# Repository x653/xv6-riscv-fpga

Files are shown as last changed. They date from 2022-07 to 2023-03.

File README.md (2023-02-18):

# xv6-riscv-fpga

Build a RISC-V computer system on fpga iCE40HX8K-EVB and run UNIX xv6 using only FOSS (free and open source hard- and software).

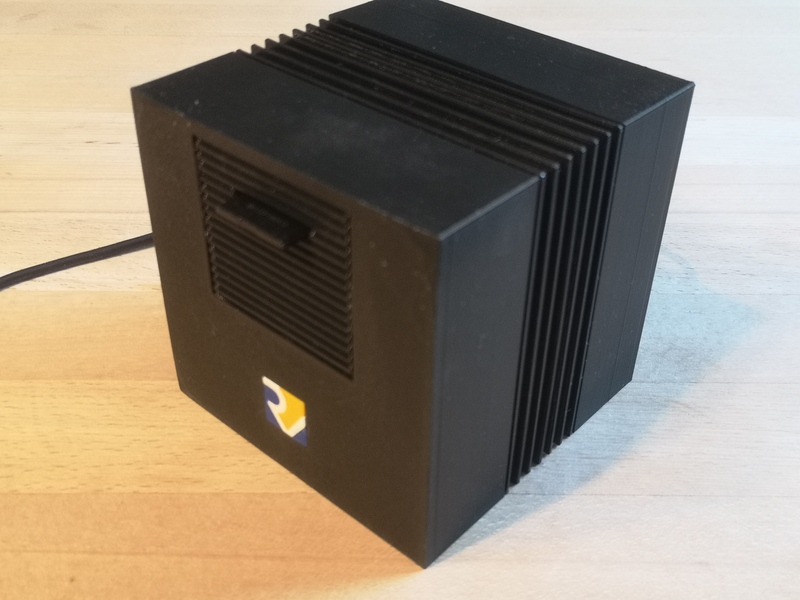
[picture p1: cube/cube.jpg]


xv6-riscv is a simple educational UNIX operating system written in ANSI-C developed and used at MIT in courses to teach operating systems. The original code is implemented for RISC-V 64 bit CPU.

In this project we will build a minimal computer system based on an fpga board capable of running UNIX xv6. We will implement only the smaller 32 bit version of RISC-V CPU and we will drop all features not explicit needed to run xv6, like floating point operation and even multiplication in hardware. The remaining core is called rv32ia_zicsr and implements only a minimal command set:

- I: Integer and logic computation

- A: atomic commands

- zicsr: control register

- privileged modes (M/S/U): machine mode, supervisor mode and user mode

- virtual memory mapping

Although our CPU does not implement multiplication and floating point operation in hardware, we will see, that all this can be done in software by linking the appropriate gcc librarys. The final computer will be able to boot UNIX xv6 and even run a homemade LISP interpreter, which is cabable of doing numerical computations even on floating point numbers.

## 01_hardware

The hardware consists of three little boards available at Olimex Ltd.

* iCE40HX8K-EVB: This development board contains the fpga chip iCE40HX8K plus a 512k Byte memory chip used as RAM.

* Olimexino 32u4: This arduino like board is used
  
  1. as programmer, to upload the fpga bitstream file to the iCE40HX8K-EVB board.
  
  2. as UART bridge, to connect a terminal to the RISCV-V CPU running UNIX xv6.
  
  3. to power everything over USB through the UEXT cable, connect the solder jumper `3.3V_E1` on iCE40HX8K-EVB. (compare schematic of [iCE40HX8K-EVB](doc/iCE40HX8K-EVB_Rev_B.pdf))

* SD-CARD: This little board holds an SD-Card containing the complete file system of UNIX xv6.

Connect the three boards according to the following picture:

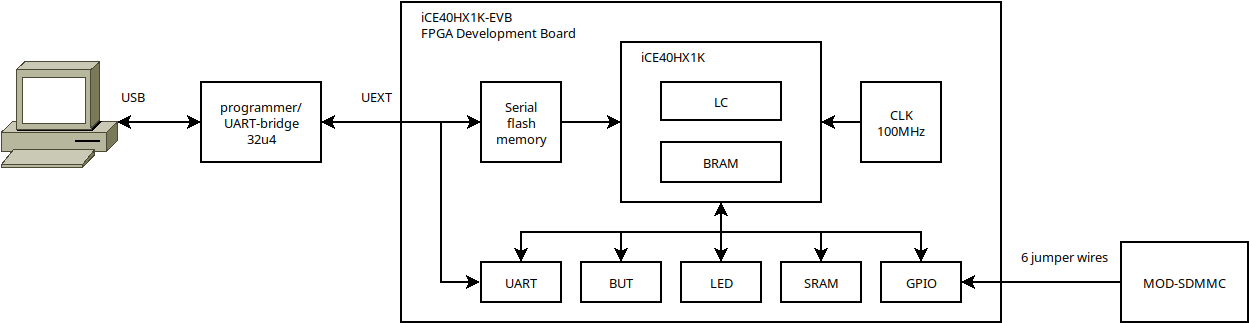
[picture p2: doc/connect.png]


* USB mini cable from Computer to Olimexino 32u4

* IDC10 cable from Olimexino 32u4 to iCE40HX8K-EVB

* 6 jumper wires from iCE40HX8K-EVB to MOD-SDMMC

| wire | iCE40HX8K-EVB<br/>JTAG1 connector | MOD-SDMMC<br/>UEXT connector |
| --- | --- | --- |
| +3.3V | 6 - VCC | 1 - VCC |
| GND | 5 - GND | 2 - GND |
| SDI - serial data in  | 2 - TDI (PIO1_00) | 7 - MISO |
| SDO - serial data out | 3 - TDO (PIO1_03) | 8 - MOSI |
| SCK - serial clock | 4 - TCK (PIO1_02) | 9 - SCK |
| CSX- chip select not  | 1 - TMS (PIO1_01) | 10 - #SS |

## 02_software

### 02.1_oss-cad-suite

The fpga iCE40HX8K has the nice property, that it can be programmed with FOSS free and open source software. This can be done with the toolchain project icestorm provided by Clifford Wold. The complete toolchain (yosys, icestorm, place and route, programmer) is available as bundle at [GitHub - YosysHQ/oss-cad-suite-build: Multi-platform nightly builds of open source digital design and verification tools](https://github.com/YosysHQ/oss-cad-suite-build/).

- Install oss-cad-suite and copy the folder to `/opt/oss-cad-suite`

### 02.1_gcc-toolchain for RISC-V

The toolchain with c-compiler can be downloaded from the following site. In order to be able to build code for the rv32ia_zicsr version we need a toolchain with multilib and gcc-libary implementation for rv32i.

Attention: Download rv64imc with multilib rv32i and copy folder to `/opt/riscv`

[GitHub - stnolting/riscv-gcc-prebuilt: 📦 Prebuilt RISC-V GCC toolchains for x64 Linux.](https://github.com/stnolting/riscv-gcc-prebuilt)

## 03_build

### 03.1_compile bootloader

* Build the firmware, which implements a bootloader, that reads the SD-CARD. The bootloader than seaches for an ELF file containing the kernel xv6. Loads the kernel into memory and starts the kernel. 

```
$ cd fpga/boot
$ make
```

### 03.2_synthesize and upload to fpga iCE40HX8K-EVB

The fpga iCE40HX8K contains the whole hardware of our computer system:

* CPU: RV32ia_zicsr

* BOOT: Memory preloaded with bootloader

* UART: Connects the terminal to xv6 shell

* SPI: Connects the SD-Card containing the file system

To build the fpga hardware connect your computer with the programmer Olimexino 32u4 and run:

```
$ cd fpga
$ make
```

### 03.3_compile xv6-riscv

* Build the software, composed of kernel and user programms and write everything on the file system. 

```
$ cd xv6-riscv
$ make
$ make fs.img
```

* Write the image `fs.img` on a SD-Card.

## 04_Run

### 04_1_run xv6

Now connect to RV32ia_zicsr with USB and start a terminal session (i.e. tio). Start RV32ia_zicsr and see the welcome message. Insert the SD-Card into the reader and see if RV32 can boot UNIX xv6 from the file system.

```
$ tio -m INLCRNL /dev/ttyACM0
 ___ ___ ___  ___  __   __
| _ \_ _/ __|/ __|_\ \ / /
|   /| |\__ \ (_|___\ V / 
|_|_\___|___/\___|   \_/  

Processor: rv32ia @32MHz V1.2

0x00001000 BOOT (12 KB)
0x02000000 CLINT
0x0C000000 PLIC
0x10000000 UART
0x10001000 SD-CARD
0x80000000 RAM (512 KB)

sb_magic 0x10203040.OK
e_magic  0x464c457f..OK
   p_type     p_addr     p_filesz   load
0  0x70000003 0x00000000 0x00000025 
1  0x00000001 0x80000000 0x00009138 OK
2  0x00000001 0x8000a000 0x0000003c OK
e_entry  0x80000000

Welcome to rv32ia 6th Edition UNIX

xv6 kernel is booting

init: starting sh
$ 
```

### 04.2_unix commands

Now that you have access to the shell you can launch UNIX commands.

```
$ ls
.              1 1 1296
..             1 1 1296
xv6.kernel     2 2 45676
README         2 3 1982
let            2 4 102
sqrt           2 5 443
sqrt2          2 6 467
fib            2 7 429
cat            2 8 4016
echo           2 9 3708
forktest       2 10 2128
grind          2 11 7952
grep           2 12 4612
init           2 13 3988
kill           2 14 3672
ln             2 15 3704
ls             2 16 4536
mkdir          2 17 3740
rm             2 18 3736
sh             2 19 7936
wc             2 20 4176
zombie         2 21 3592
stressfs       2 22 3896
uptime         2 23 3820
usertests      2 24 40660
lisp           2 25 23432
hello          2 26 3640
mem            2 27 4184
console        3 28 0
$ cat README
xv6 is a re-implementation of Dennis Ritchie's and Ken Thompson's Unix
Version 6 (v6).  xv6 loosely follows the structure and style of v6,
but is implemented for a modern RISC-V multiprocessor using ANSI C.

ACKNOWLEDGMENTS

xv6 is inspired by John Lions's Commentary on UNIX 6th Edition (Peer
to Peer Communications; ISBN: 1-57398-013-7; 1st edition (June 14,
2000)). See also https://pdos.csail.mit.edu/6.828/, which
provides pointers to on-line resources for v6.

The following people have made contributions: Russ Cox (context switching,
locking), Cliff Frey (MP), Xiao Yu (MP), Nickolai Zeldovich, and Austin
Clements.

We are also grateful for the bug reports and patches contributed by
Silas Boyd-Wickizer, Anton Burtsev, Dan Cross, Cody Cutler, Mike CAT,
Tej Chajed, eyalz800, Nelson Elhage, Saar Ettinger, Alice Ferrazzi,
Nathaniel Filardo, Peter Froehlich, Yakir Goaron,Shivam Handa, Bryan
Henry, Jim Huang, Alexander Kapshuk, Anders Kaseorg, kehao95, Wolfgang
Keller, Eddie Kohler, Austin Liew, Imbar Marinescu, Yandong Mao, Matan
Shabtay, Hitoshi Mitake, Carmi Merimovich, Mark Morrissey, mtasm, Joel
Nider, Greg Price, Ayan Shafqat, Eldar Sehayek, Yongming Shen, Cam
Tenny, tyfkda, Rafael Ubal, Warren Toomey, Stephen Tu, Pablo Ventura,
Xi Wang, Keiichi Watanabe, Nicolas Wolovick, wxdao, Grant Wu, Jindong
Zhang, Icenowy Zheng, and Zou Chang Wei.

The code in the files that constitute xv6 is
Copyright 2006-2019 Frans Kaashoek, Robert Morris, and Russ Cox.

ERROR REPORTS

Please send errors and suggestions to Frans Kaashoek and Robert Morris
(kaashoek,rtm@mit.edu). The main purpose of xv6 is as a teaching
operating system for MIT's 6.828, so we are more interested in
simplifications and clarifications than new features.

BUILDING AND RUNNING XV6

You will need a RISC-V "newlib" tool chain from
https://github.com/riscv/riscv-gnu-toolchain, and qemu compiled for
riscv64-softmmu. Once they are installed, and in your shell
search path, you can run "make qemu".
$ 
```

### 04.3_run LISP

and even run LISP on a computer system that runs UNIX on a home made CPU! 

```
$ lisp
lisp v6
sizeof pair: 2
size of number: 4
size of float: 4
size of (char*): 4
lisp> (+ 2 4)
6
lisp> 
```

## 05_cube

Finally we print case with a 3d-Printer. The case is a miniatur replica of the classic computer NeXTcube (https://en.wikipedia.org/wiki/NeXTcube). All components are mounted on trays, which can be pushed in the cube (10cm x 10cm x 10cm).

All the parts are modelled with free software tools.

- [blender](https://blender.org) is a very powerfull 3D modelling software. All parts of the cube are modelled with blender. You can edit the blender files and change details on the design. The blender-design files can than be exported to STL-format, a common 3D-file format used for 3D-printing.
- [prusa-slic3r](https://www.prusa3d.com). This is the slicer software for 3D-Printers from the manufacturer Prusa. This programm is used to convert the STL-files to printerspecific gcode-files.

The subfolder `files/` containes the blender files and the corresponging STL-files.

### 05.1_inside

The modules are mounted on trays with little screws (M3x5/M2.4x5 selfcutting). From left to right:

1. Olimexino 32u4: Programmer/UART bridge
2. iCE40HX8K-EVB: fpga development board
3. SD-Card reader
4. Thinker

# 

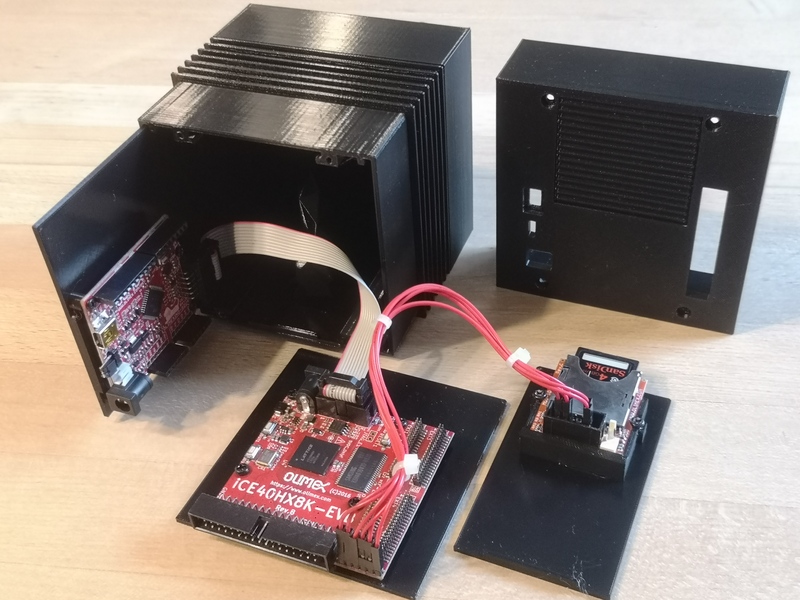
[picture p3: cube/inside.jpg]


### 05.2_rear

On the rear cover you see connectors for power supply (5V), 34 pin GPIO and the USB connector which has dual usage:

1. upload bitstream files to iCE40 fpga
2. communicate to Hack-Computer over UART

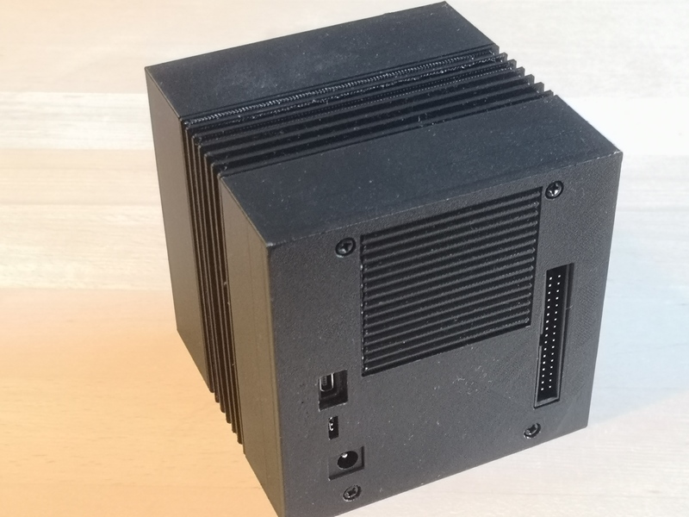
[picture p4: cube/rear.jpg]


# 

## 06_License

Copyright 2023 Michael Schröder mi.schroeder@netcologne.de

<br />Dieses Werk ist lizenziert unter einer <a rel="license" href="http://creativecommons.org/licenses/by/4.0/">Creative Commons Namensnennung 4.0 International Lizenz</a>.

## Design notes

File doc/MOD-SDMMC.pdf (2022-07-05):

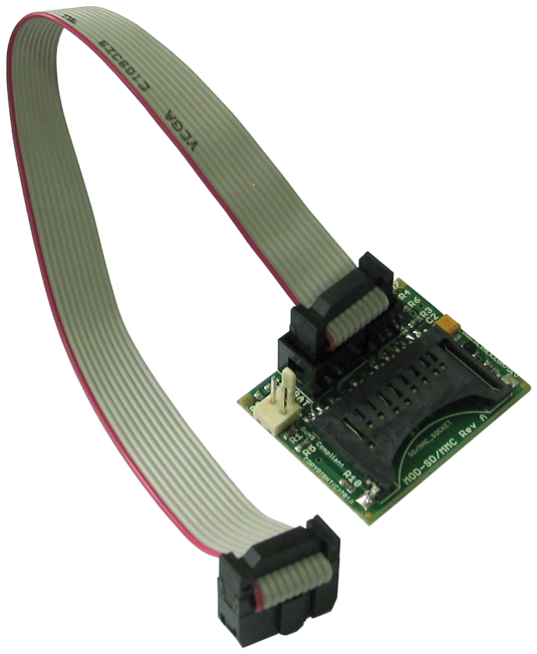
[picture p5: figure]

# MOD-SD_MMC development board User's manual

All boards produced by Olimex are ROHS compliant

Revision B, November 2013

## Copyright(c) 2013, OLIMEX Ltd, All rights reserved

Page 1

## INTRODUCTION:

MOD-SDMMC is module board with SD/MMC connector on it. The board is excellent extension for development boards without SD/MMC, but with UEXT. You can connect the board via its 10 pin cable to the UEXT of another board and en-joy the enormous variety of SD/MMC applications.

## BOARD FEATURES:

- UEXT connector
- BAT connector
- SD/MMC_SOCKET
- 10 pin cable for the UEXT connector
- FR-4, 1.5 mm, red soldermask, component print
- Dimensions:38.00 x 31.00mm (1.50 x 1.22")

## ELECTROSTATIC WARNING:

The MOD-SDMMC board is shipped in protective anti-static packaging. The board must not be subject to high electrostatic potentials. General practice for working with static sensitive devices should be applied when working with this board.

## BOARD USE REQUIREMENTS:

Cables: | The boards is shipped with 10 pin cable for the UEXT connector.
Hardware: | Some of OLIMEX's boards with UEXT.

Page 2

## SCHEMATIC:

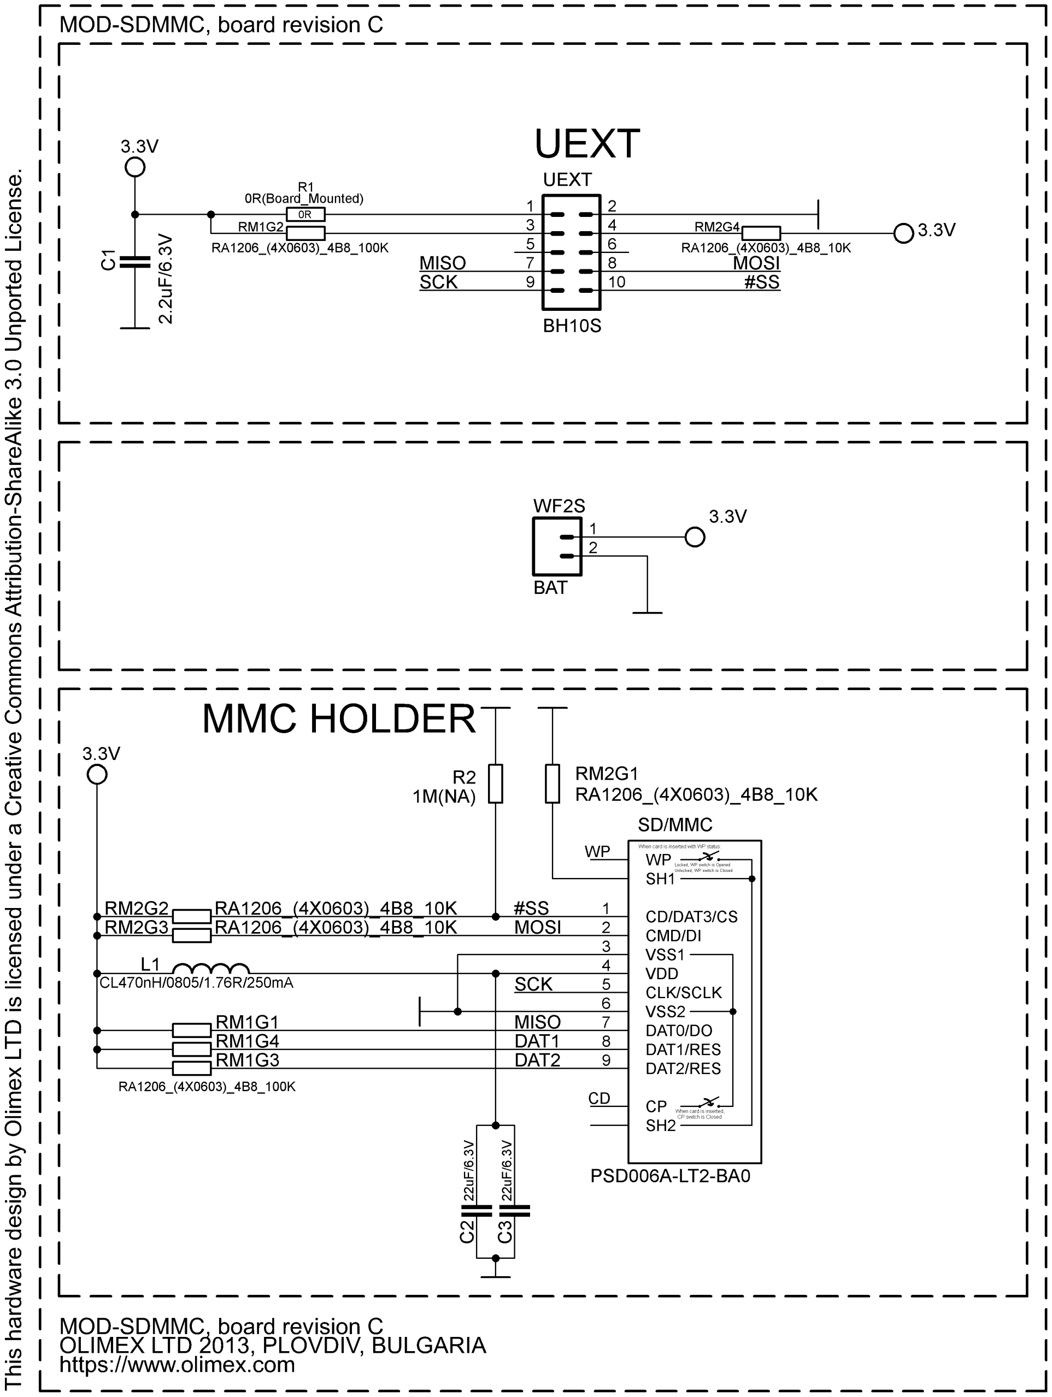
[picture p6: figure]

You can find a searchable schematic at the web page of the MOD-SDMMC.

Page 3

## BOARD LAYOUT:

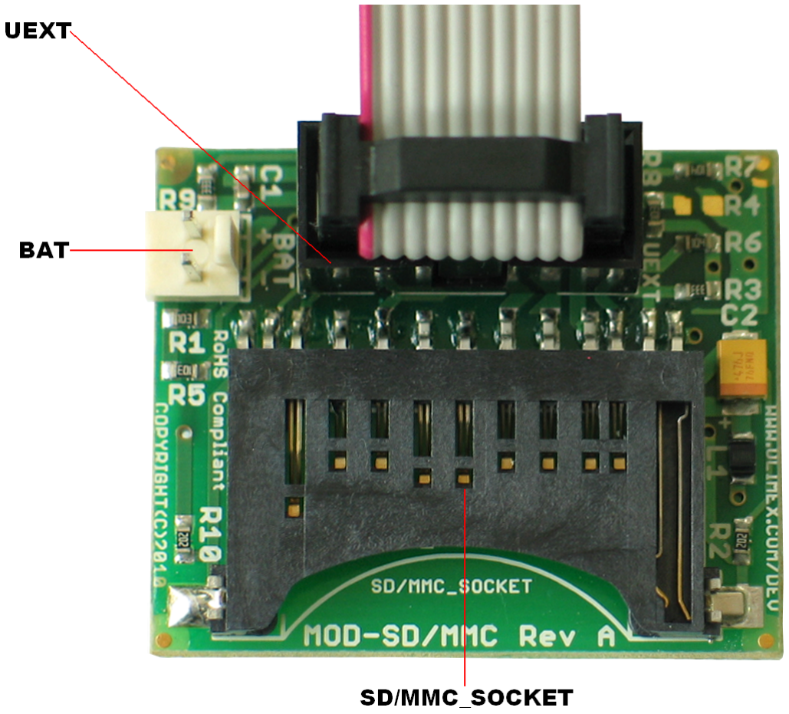
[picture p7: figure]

## POWER SUPPLY CIRCUIT:

MOD-SD_MMC can take power from:
– | + 3.3V via BAT connector.
– | UEXT connector

Page 4

## EXTERNAL CONNECTORS DESCRIPTION: UEXT:

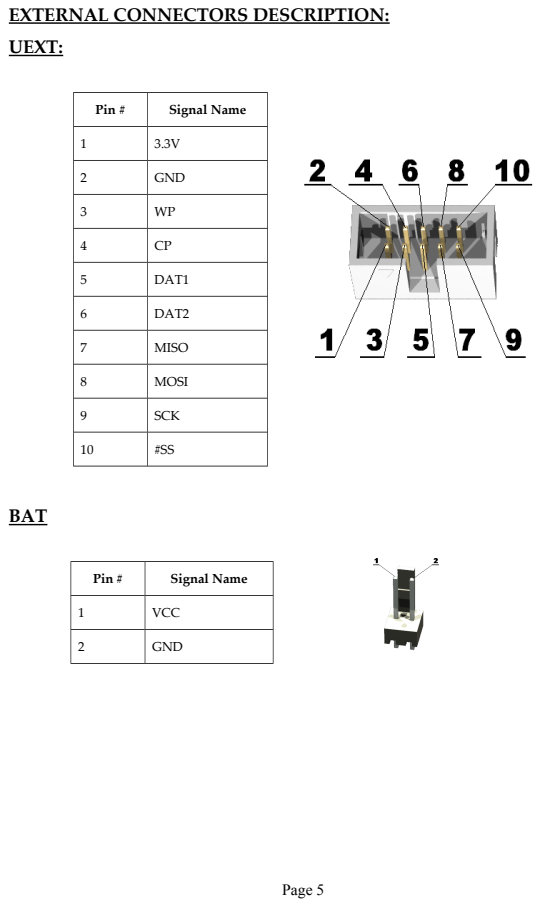
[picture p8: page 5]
Pin #; Signal Name; GND; DAT1; DAT2; MISO; MOSI; SCK; BAT; VCC; Page 5

## SD/MMC:

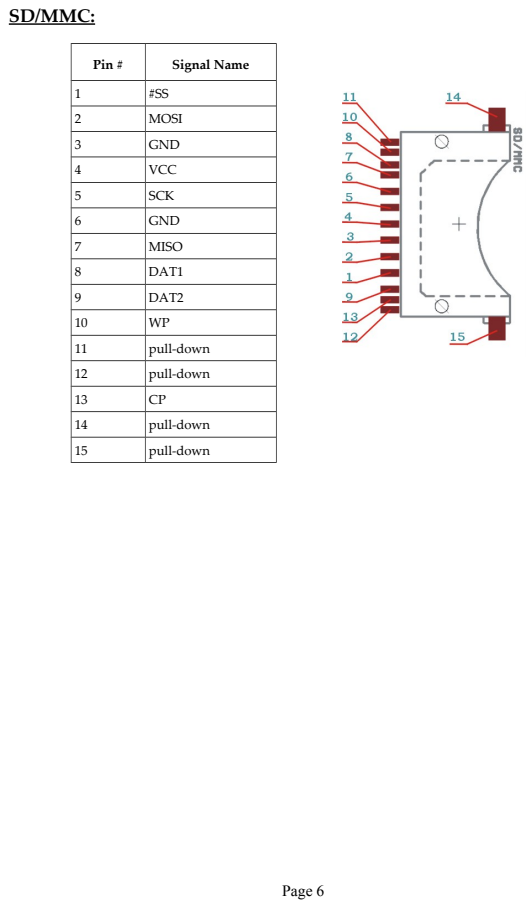
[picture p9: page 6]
Pin #; Signal Name; MOSI; GND; VCC; SCK; MISO; DAT1; DAT2; pull-down; Page 6

## MECHANICAL DIMENSIONS:

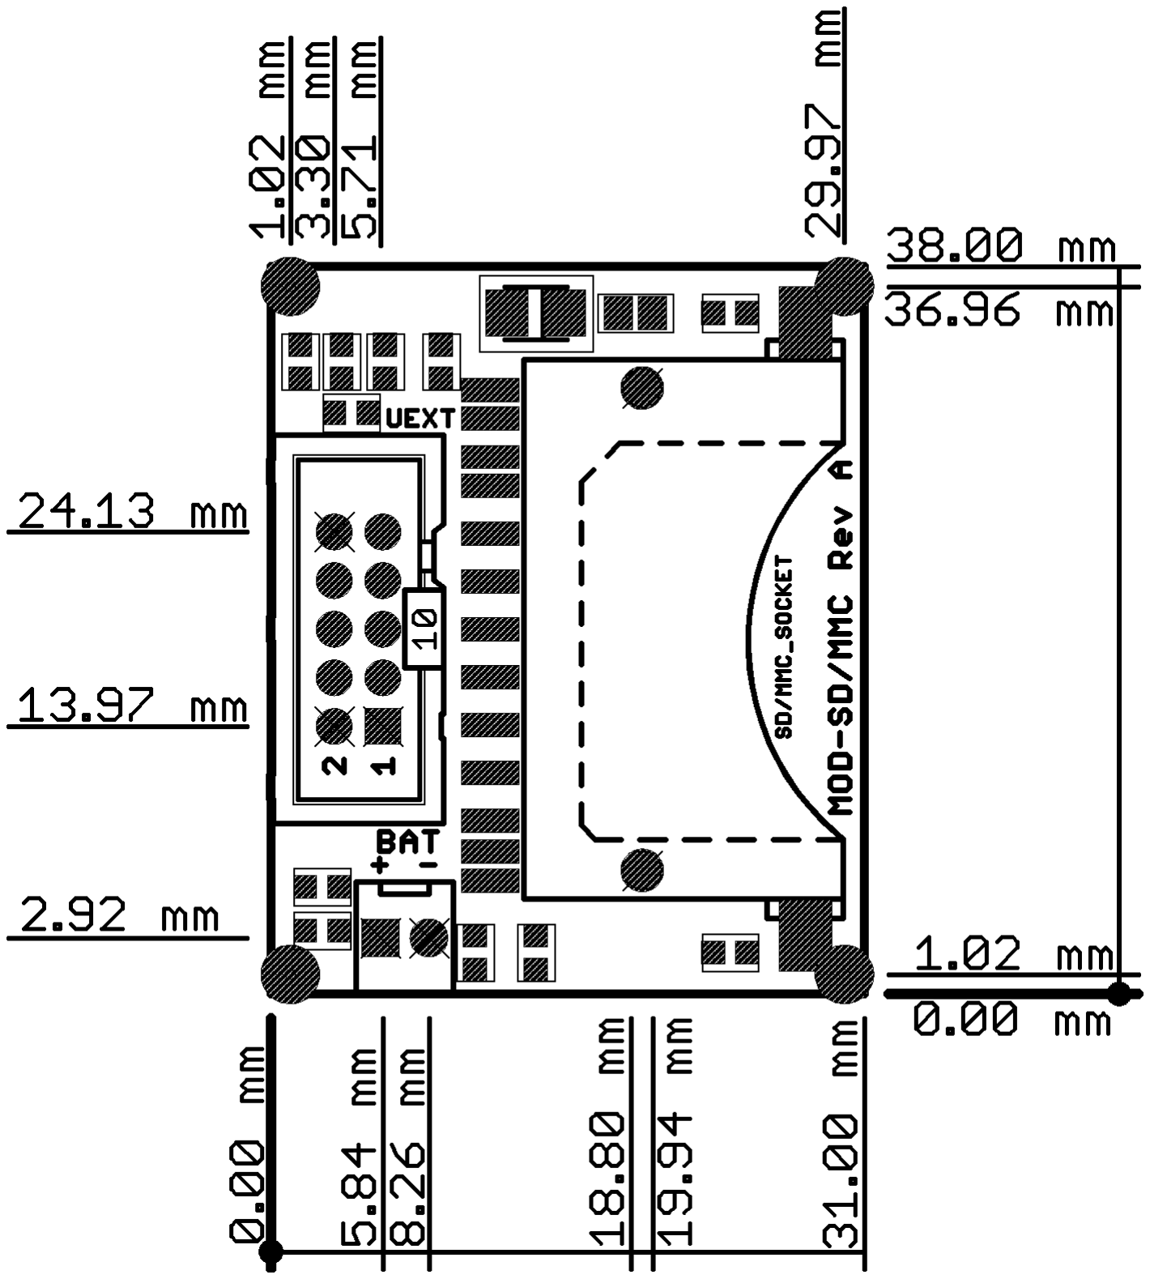
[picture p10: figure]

Page 7

## ORDER CODE:

MOD-SDMMC - assembled and tested board

How to order?
You can order directly from our web shop or via our distributors. Check our web site https://www.olimex.com for more info.

### Revision history:

Board's revision: | Rev. A, April 2011
| Rev. C, November 2013
Manual's revision: | Rev. Initial, June 2011
| Rev. B, November 2013

Page 8

Disclaimer:

© 2013 Olimex Ltd. All rights reserved. Olimex®, logo and combinations thereof, are registered trademarks of Olimex Ltd. Other terms and product names may be trademarks of others.
The information in this document is provided in connection with Olimex products. No license, express or implied or otherwise, to any intellectual property right is granted by this document or in connection with the sale of Olimex products.
Neither the whole nor any part of the information contained in or the product described in this document may be adapted or reproduced in any material from except with the prior written permission of the copyright holder.
The product described in this document is subject to continuous development and improvements. All particulars of the product and its use contained in this document are given by OLIMEX in good faith. However all warranties implied or expressed including but not limited to implied warranties of merchantability or fitness for purpose are excluded.
This document is intended only to assist the reader in the use of the product. OLIMEX Ltd. shall not be liable for any loss or damage arising from the use of any information in this document or any error or omission in such information or any incorrect use of the product.

Page 9

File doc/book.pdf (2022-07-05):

# xv6: a simple, Unix-like teaching operating system

Russ Cox | Frans Kaashoek | Robert Morris
| May 19, 2022

2

# Contents

1 Operating system interfaces | 9
2 Operating system organization | 21
3 Page tables | 31

3

4 Traps and system calls | 43
4.1 RISC-V trap machinery | 44
4.2 Traps from user space | 45
4.3 Code: Calling system calls | 47
4.4 Code: System call arguments | 47
4.5 Traps from kernel space | 48
4.6 Page-fault exceptions | 48
4.7 Real world | 50
4.8 Exercises | 51
5 Interrupts and device drivers | 53
5.1 Code: Console input | 53
5.2 Code: Console output | 54
5.3 Concurrency in drivers | 55
5.4 Timer interrupts | 55
5.5 Real world | 56
5.6 Exercises | 57
6 Locking | 59
6.1 Race conditions | 60
6.2 Code: Locks | 62
6.3 Code: Using locks | 63
6.4 Deadlock and lock ordering | 64
6.5 Re-entrant locks | 66
6.6 Locks and interrupt handlers | 67
6.7 Instruction and memory ordering | 67
6.8 Sleep locks | 68
6.9 Real world | 68
6.10 Exercises | 69
7 Scheduling | 71
7.1 Multiplexing | 71
7.2 Code: Context switching | 72
7.3 Code: Scheduling | 73
7.4 Code: mycpu and myproc | 74
7.5 Sleep and wakeup | 75
7.6 Code: Sleep and wakeup | 78
7.7 Code: Pipes | 79
7.8 Code: Wait, exit, and kill | 80
7.9 Process Locking | 81
7.10 Real world | 82
7.11 Exercises | 83

4

8 File system | 85
8.1 Overview | 85
8.2 Buffer cache layer | 87
8.3 Code: Buffer cache | 87
8.4 Logging layer | 88
8.5 Log design | 89
8.6 Code: logging | 90
8.7 Code: Block allocator | 91
8.8 Inode layer | 91
8.9 Code: Inodes | 93
8.10 Code: Inode content | 94
8.11 Code: directory layer | 95
8.12 Code: Path names | 96
8.13 File descriptor layer | 97
8.14 Code: System calls | 97
8.15 Real world | 99
8.16 Exercises | 100
9 Concurrency revisited | 101
9.1 Locking patterns | 101
9.2 Lock-like patterns | 102
9.3 No locks at all | 102
9.4 Parallelism | 103
9.5 Exercises | 104
10 Summary | 105

5

6

# Foreword and acknowledgments

This is a draft text intended for a class on operating systems. It explains the main concepts of operating systems by studying an example kernel, named xv6. xv6 is modeled on Dennis Ritchie’s and Ken Thompson’s Unix Version 6 (v6) [15]. xv6 loosely follows the structure and style of v6, but is implemented in ANSI C [6] for a multi-core RISC-V [13].
This text should be read along with the source code for xv6, an approach inspired by John Lions’ Commentary on UNIX 6th Edition [10]. See https://pdos.csail.mit.edu/6. S081 (https://pdos.csail.mit.edu/6.S081) for pointers to on-line resources for v6 and xv6, including several lab assignments using xv6.
We have used this text in 6.828 and 6.S081, the operating systems classes at MIT. We thank the faculty, teaching assistants, and students of those classes who have all directly or indirectly contributed to xv6. In particular, we would like to thank Adam Belay, Austin Clements, and Nickolai Zeldovich. Finally, we would like to thank people who emailed us bugs in the text or suggestions for improvements: Abutalib Aghayev, Sebastian Boehm, Anton Burtsev, Raphael Carvalho, Tej Chajed, Rasit Eskicioglu, Color Fuzzy, Wojciech Gac, Giuseppe, Tao Guo, Haibo Hao, Muhammed Mourad, Naoki Hayama, Robert Hilderman, Wolfgang Keller, Henry Laih, Jin Li, Austin Liew, Pavan Maddamsetti, Jacek Masiulaniec, Michael McConville, m3hm00d, miguelgvieira, Mark Morrissey, Harry Pan, Askar Safin, Salman Shah, Adeodato Simó, Ruslan Savchenko, Pawel Szczurko, Warren Toomey, tyfkda, tzerbib, Vanush Vaswani, Xi Wang, Sam Whitlock, and Zou Chang Wei. If you spot errors or have suggestions for improvement, please send email to Frans Kaashoek and Robert Morris (kaashoek,rtm@csail.mit.edu).

7

8

# Chapter 1

# Operating system interfaces

The job of an operating system is to share a computer among multiple programs and to provide a more useful set of services than the hardware alone supports. An operating system manages and abstracts the low-level hardware, so that, for example, a word processor need not concern itself with which type of disk hardware is being used. An operating system shares the hardware among multiple programs so that they run (or appear to run) at the same time. Finally, operating systems provide controlled ways for programs to interact, so that they can share data or work together.
An operating system provides services to user programs through an interface. Designing a good interface turns out to be difficult. On the one hand, we would like the interface to be simple and narrow because that makes it easier to get the implementation right. On the other hand, we may be tempted to offer many sophisticated features to applications. The trick in resolving this tension is to design interfaces that rely on a few mechanisms that can be combined to provide much generality. This book uses a single operating system as a concrete example to illustrate operating system concepts. That operating system, xv6, provides the basic interfaces introduced by Ken Thompson and Dennis Ritchie’s Unix operating system [15], as well as mimicking Unix’s internal design. Unix provides a narrow interface whose mechanisms combine well, offering a surprising degree of generality. This interface has been so successful that modern operating systems—BSD, Linux, macOS, Solaris, and even, to a lesser extent, Microsoft Windows—have Unix-like interfaces. Understanding xv6 is a good start toward understanding any of these systems and many others.
As Figure 1.1 shows, xv6 takes the traditional form of a kernel, a special program that provides services to running programs. Each running program, called a process, has memory containing instructions, data, and a stack. The instructions implement the program’s computation. The data are the variables on which the computation acts. The stack organizes the program’s procedure calls. A given computer typically has many processes but only a single kernel.
When a process needs to invoke a kernel service, it invokes a system call, one of the calls in the operating system’s interface. The system call enters the kernel; the kernel performs the service and returns. Thus a process alternates between executing in user space and kernel space.
The kernel uses the hardware protection mechanisms provided by a CPU¹
to ensure that each

1This text generally refers to the hardware element that executes a computation with the term CPU, an acronym for central processing unit. Other documentation (e.g., the RISC-V specification) also uses the words processor, core, and hart instead of CPU.

9

Kernel

shell | cat user
space

kernel
space

system
call

Figure 1.1: A kernel and two user processes.

process executing in user space can access only its own memory. The kernel executes with the hardware privileges required to implement these protections; user programs execute without those privileges. When a user program invokes a system call, the hardware raises the privilege level and starts executing a pre-arranged function in the kernel.
The collection of system calls that a kernel provides is the interface that user programs see. The xv6 kernel provides a subset of the services and system calls that Unix kernels traditionally offer. Figure 1.2 lists all of xv6’s system calls.
The rest of this chapter outlines xv6’s services—processes, memory, file descriptors, pipes, and a file system—and illustrates them with code snippets and discussions of how the shell, Unix’s command-line user interface, uses them. The shell’s use of system calls illustrates how carefully they have been designed.
The shell is an ordinary program that reads commands from the user and executes them. The fact that the shell is a user program, and not part of the kernel, illustrates the power of the system call interface: there is nothing special about the shell. It also means that the shell is easy to replace; as a result, modern Unix systems have a variety of shells to choose from, each with its own user interface and scripting features. The xv6 shell is a simple implementation of the essence of the Unix Bourne shell. Its implementation can be found at (user/sh.c:1). (https://github.com/mit-pdos/xv6-riscv/blob/riscv//user/sh.c#L1)

## 1.1 Processes and memory

An xv6 process consists of user-space memory (instructions, data, and stack) and per-process state private to the kernel. Xv6 time-shares processes: it transparently switches the available CPUs among the set of processes waiting to execute. When a process is not executing, xv6 saves its CPU registers, restoring them when it next runs the process. The kernel associates a process identifier, or PID, with each process.
A process may create a new process using the fork system call. Fork gives the new process exactly the same memory contents (both instructions and data) as the calling process. Fork returns in both the original and new processes. In the original process, fork returns the new process’s PID. In the new process, fork returns zero. The original and new processes are often called the parent and child.
For example, consider the following program fragment written in the C programming language [6]:

int pid = fork();

10

System call | Description
int fork() | Create a process, return child’s PID.
int exit(int status) | Terminate the current process; status reported to wait(). No return.
int wait(int *status) | Wait for a child to exit; exit status in *status; returns child PID.
int kill(int pid) | Terminate process PID. Returns 0, or -1 for error.
int getpid() | Return the current process’s PID.
int sleep(int n) | Pause for n clock ticks.
int exec(char *file, char *argv[]) Load a file and execute it with arguments; only returns if error.
char *sbrk(int n) | Grow process’s memory by n bytes. Returns start of new memory.
int open(char *file, int flags) | Open a file; flags indicate read/write; returns an fd (file descriptor).
int write(int fd, char *buf, int n) | Write n bytes from buf to file descriptor fd; returns n.
int read(int fd, char *buf, int n) | Read n bytes into buf; returns number read; or 0 if end of file.
int close(int fd) | Release open file fd.
int dup(int fd) | Return a new file descriptor referring to the same file as fd.
int pipe(int p[]) | Create a pipe, put read/write file descriptors in p[0] and p[1].
int chdir(char *dir) | Change the current directory.
int mkdir(char *dir) | Create a new directory.
int mknod(char *file, int, int) | Create a device file.
int fstat(int fd, struct stat *st) | Place info about an open file into *st.
int stat(char *file, struct stat *st) Place info about a named file into *st.
int link(char *file1, char *file2) | Create another name (file2) for the file file1.
int unlink(char *file) | Remove a file.

Figure 1.2: Xv6 system calls. If not otherwise stated, these calls return 0 for no error, and -1 if there’s an error.

if(pid > 0){
printf("parent: child=%d\n", pid); pid = wait((int *) 0);
printf("child %d is done\n", pid); } else if(pid == 0){
printf("child: exiting\n"); exit(0);
} else {
printf("fork error\n");
}

The exit system call causes the calling process to stop executing and to release resources such as memory and open files. Exit takes an integer status argument, conventionally 0 to indicate success and 1 to indicate failure. The wait system call returns the PID of an exited (or killed) child of the current process and copies the exit status of the child to the address passed to wait; if none of the caller’s children has exited, wait waits for one to do so. If the caller has no children, wait immediately returns -1. If the parent doesn’t care about the exit status of a child, it can pass a 0 address to wait.

11

In the example, the output lines

parent: child=1234
child: exiting

might come out in either order (or even intermixed), depending on whether the parent or child gets to its printf call first. After the child exits, the parent’s wait returns, causing the parent to print

parent: child 1234 is done

Although the child has the same memory contents as the parent initially, the parent and child are executing with different memory and different registers: changing a variable in one does not affect the other. For example, when the return value of wait is stored into pid in the parent process, it doesn’t change the variable pid in the child. The value of pid in the child will still be zero.
The exec system call replaces the calling process’s memory with a new memory image loaded from a file stored in the file system. The file must have a particular format, which specifies which part of the file holds instructions, which part is data, at which instruction to start, etc. Xv6 uses the ELF format, which Chapter 3 discusses in more detail. When exec succeeds, it does not return to the calling program; instead, the instructions loaded from the file start executing at the entry point declared in the ELF header. Exec takes two arguments: the name of the file containing the executable and an array of string arguments. For example:

char *argv[3];

argv[0] = "echo";
argv[1] = "hello";
argv[2] = 0;
exec("/bin/echo", argv);
printf("exec error\n");

This fragment replaces the calling program with an instance of the program /bin/echo running with the argument list echo hello. Most programs ignore the first element of the argument array, which is conventionally the name of the program.
The xv6 shell uses the above calls to run programs on behalf of users. The main structure of the shell is simple; see main The main loop reads a line of input from the user with getcmd. Then it calls fork, which creates a copy of the shell process. The parent calls wait, while the child runs the command. For example, if the user had typed “echo hello” to the shell, runcmd would have been called with “echo hello” as the argument. runcmd runs the actual command. For “echo hello”, it would call exec If exec succeeds then the child will execute instructions from echo instead of runcmd. At some point echo will call exit, which will cause the parent to return
from wait in main
You might wonder why fork and exec are not combined in a single call; we will see later that the shell exploits the separation in its implementation of I/O redirection. To avoid the wastefulness of creating a duplicate process and then immediately replacing it (with exec), operating kernels optimize the implementation of fork for this use case by using virtual memory techniques such as copy-on-write (see Section 4.6).

12

Xv6 allocates most user-space memory implicitly: fork allocates the memory required for the child’s copy of the parent’s memory, and exec allocates enough memory to hold the executable file. A process that needs more memory at run-time (perhaps for malloc) can call sbrk(n) to grow its data memory by n bytes; sbrk returns the location of the new memory.

## 1.2 I/O and File descriptors

A file descriptor is a small integer representing a kernel-managed object that a process may read from or write to. A process may obtain a file descriptor by opening a file, directory, or device, or by creating a pipe, or by duplicating an existing descriptor. For simplicity we’ll often refer to the object a file descriptor refers to as a “file”; the file descriptor interface abstracts away the differences between files, pipes, and devices, making them all look like streams of bytes. We’ll refer to input and output as I/O.
Internally, the xv6 kernel uses the file descriptor as an index into a per-process table, so that every process has a private space of file descriptors starting at zero. By convention, a process reads from file descriptor 0 (standard input), writes output to file descriptor 1 (standard output), and writes error messages to file descriptor 2 (standard error). As we will see, the shell exploits the convention to implement I/O redirection and pipelines. The shell ensures that it always has three file descriptors open which are by default file descriptors for the console.
The read and write system calls read bytes from and write bytes to open files named by file descriptors. The call read(fd, buf, n) reads at most n bytes from the file descriptor fd, copies them into buf, and returns the number of bytes read. Each file descriptor that refers to a file has an offset associated with it. Read reads data from the current file offset and then advances that offset by the number of bytes read: a subsequent read will return the bytes following the ones returned by the first read. When there are no more bytes to read, read returns zero to indicate the end of the file.
The call write(fd, buf, n) writes n bytes from buf to the file descriptor fd and returns the number of bytes written. Fewer than n bytes are written only when an error occurs. Like read, write writes data at the current file offset and then advances that offset by the number of bytes written: each write picks up where the previous one left off.
The following program fragment (which forms the essence of the program cat) copies data from its standard input to its standard output. If an error occurs, it writes a message to the standard error.

char buf[512];
int n;

for(;;){
n = read(0, buf, sizeof buf); if(n == 0)
break;
if(n < 0){
fprintf(2, "read error\n");

13

exit(1);
}
if(write(1, buf, n) != n){ fprintf(2, "write error\n"); exit(1);
}
}
The important thing to note in the code fragment is that cat doesn’t know whether it is reading from a file, console, or a pipe. Similarly cat doesn’t know whether it is printing to a console, a file, or whatever. The use of file descriptors and the convention that file descriptor 0 is input and file descriptor 1 is output allows a simple implementation of cat.
The close system call releases a file descriptor, making it free for reuse by a future open, pipe, or dup system call (see below). A newly allocated file descriptor is always the lowestnumbered unused descriptor of the current process.
File descriptors and fork interact to make I/O redirection easy to implement. Fork copies the parent’s file descriptor table along with its memory, so that the child starts with exactly the same open files as the parent. The system call exec replaces the calling process’s memory but preserves its file table. This behavior allows the shell to implement I/O redirection by forking, reopening chosen file descriptors in the child, and then calling exec to run the new program. Here is a simplified version of the code a shell runs for the command cat < input.txt:

char *argv[2];

argv[0] = "cat";
argv[1] = 0;
if(fork() == 0) {
close(0);
open("input.txt", O_RDONLY); exec("cat", argv);
}
After the child closes file descriptor 0, open is guaranteed to use that file descriptor for the newly opened input.txt: 0 will be the smallest available file descriptor. Cat then executes with file descriptor 0 (standard input) referring to input.txt. The parent process’s file descriptors are not changed by this sequence, since it modifies only the child’s descriptors.
The code for I/O redirection in the xv6 shell works in exactly this way Recall that at this point in the code the shell has already forked the child shell and that runcmd will call exec to load the new program.
The second argument to open consists of a set of flags, expressed as bits, that control what open does. The possible values are defined in the file control (fcntl) header O_RDONLY, O_WRONLY, O_RDWR, O_CREATE, and O_TRUNC, which instruct open to open the file for reading, or for writing, or for both reading and writing, to create the file if it doesn’t exist, and to truncate the file to zero length.
Now it should be clear why it is helpful that fork and exec are separate calls: between the two, the shell has a chance to redirect the child’s I/O without disturbing the I/O setup of the main

14 shell. One could instead imagine a hypothetical combined forkexec system call, but the options for doing I/O redirection with such a call seem awkward. The shell could modify its own I/O setup before calling forkexec (and then un-do those modifications); or forkexec could take instructions for I/O redirection as arguments; or (least attractively) every program like cat could be taught to do its own I/O redirection.
Although fork copies the file descriptor table, each underlying file offset is shared between parent and child. Consider this example:

if(fork() == 0) {
write(1, "hello ", 6);
exit(0);
} else {
wait(0);
write(1, "world\n", 6);
}

At the end of this fragment, the file attached to file descriptor 1 will contain the data hello world. The write in the parent (which, thanks to wait, runs only after the child is done) picks up where the child’s write left off. This behavior helps produce sequential output from sequences of shell
commands, like (echo hello; echo world) >output.txt.
The dup system call duplicates an existing file descriptor, returning a new one that refers to the same underlying I/O object. Both file descriptors share an offset, just as the file descriptors duplicated by fork do. This is another way to write hello world into a file:

fd = dup(1);
write(1, "hello ", 6);
write(fd, "world\n", 6);

Two file descriptors share an offset if they were derived from the same original file descriptor by a sequence of fork and dup calls. Otherwise file descriptors do not share offsets, even if they resulted from open calls for the same file. Dup allows shells to implement commands like this:
ls existing-file non-existing-file > tmp1 2>&1. The 2>&1 tells the shell to give the
command a file descriptor 2 that is a duplicate of descriptor 1. Both the name of the existing file and the error message for the non-existing file will show up in the file tmp1. The xv6 shell doesn’t support I/O redirection for the error file descriptor, but now you know how to implement it.
File descriptors are a powerful abstraction, because they hide the details of what they are connected to: a process writing to file descriptor 1 may be writing to a file, to a device like the console, or to a pipe.

## 1.3 Pipes

A pipe is a small kernel buffer exposed to processes as a pair of file descriptors, one for reading and one for writing. Writing data to one end of the pipe makes that data available for reading from the other end of the pipe. Pipes provide a way for processes to communicate.

15

The following example code runs the program wc with standard input connected to the read end of a pipe.

int p[2];
char *argv[2];

argv[0] = "wc";
argv[1] = 0;

pipe(p);
if(fork() == 0) {
close(0);
dup(p[0]);
close(p[0]);
close(p[1]);
exec("/bin/wc", argv);
} else {
close(p[0]);
write(p[1], "hello world\n", 12); close(p[1]);
}

The program calls pipe, which creates a new pipe and records the read and write file descriptors in the array p. After fork, both parent and child have file descriptors referring to the pipe. The child calls close and dup to make file descriptor zero refer to the read end of the pipe, closes the file descriptors in p, and calls exec to run wc. When wc reads from its standard input, it reads from the pipe. The parent closes the read side of the pipe, writes to the pipe, and then closes the write side.
If no data is available, a read on a pipe waits for either data to be written or for all file descriptors referring to the write end to be closed; in the latter case, read will return 0, just as if the end of a data file had been reached. The fact that read blocks until it is impossible for new data to arrive is one reason that it’s important for the child to close the write end of the pipe before executing wc above: if one of wc ’s file descriptors referred to the write end of the pipe, wc would never see end-of-file.
The xv6 shell implements pipelines such as grep fork sh.c | wc -l in a manner similar
to the above code The child process creates a pipe to connect the left end of the pipeline with the right end. Then it calls fork and runcmd for the left end of the pipeline and fork and runcmd for the right end, and waits for both to finish. The right end of the pipeline may be a command that
itself includes a pipe (e.g., a | b | c), which itself forks two new child processes (one for b and
one for c). Thus, the shell may create a tree of processes. The leaves of this tree are commands and the interior nodes are processes that wait until the left and right children complete.
In principle, one could have the interior nodes run the left end of a pipeline, but doing so correctly would complicate the implementation. Consider making just the following modification: change sh.c to not fork for p->left and run runcmd(p->left) in the interior process. Then,
for example, echo hi | wc won’t produce output, because when echo hi exits in runcmd,

16 the interior process exits and never calls fork to run the right end of the pipe. This incorrect behavior could be fixed by not calling exit in runcmd for interior processes, but this fix complicates the code: now runcmd needs to know if it’s in an interior process or not. Complications also arise when not forking for runcmd(p->right). For example, with just that modification,
sleep 10 | echo hi will immediately print “hi’ and a new prompt, instead of after 10 sec-
onds; this happens because echo runs immediately and exits, not waiting for sleep to finish. Since the goal of the sh.c is to be as simple as possible, it doesn’t try to avoid creating interior processes.
Pipes may seem no more powerful than temporary files: the pipeline
echo hello world | wc

could be implemented without pipes as

echo hello world >/tmp/xyz; wc </tmp/xyz

Pipes have at least four advantages over temporary files in this situation. First, pipes automatically clean themselves up; with the file redirection, a shell would have to be careful to remove /tmp/xyz when done. Second, pipes can pass arbitrarily long streams of data, while file redirection requires enough free space on disk to store all the data. Third, pipes allow for parallel execution of pipeline stages, while the file approach requires the first program to finish before the second starts. Fourth, if you are implementing inter-process communication, pipes’ blocking reads and writes are more efficient than the non-blocking semantics of files.

## 1.4 File system

The xv6 file system provides data files, which contain uninterpreted byte arrays, and directories, which contain named references to data files and other directories. The directories form a tree, starting at a special directory called the root. A path like /a/b/c refers to the file or directory named c inside the directory named b inside the directory named a in the root directory /. Paths that don’t begin with / are evaluated relative to the calling process’s current directory, which can be changed with the chdir system call. Both these code fragments open the same file (assuming all the directories involved exist):

chdir("/a");
chdir("b");
open("c", O_RDONLY);

open("/a/b/c", O_RDONLY);

The first fragment changes the process’s current directory to /a/b; the second neither refers to nor changes the process’s current directory.
There are system calls to create new files and directories: mkdir creates a new directory, open with the O_CREATE flag creates a new data file, and mknod creates a new device file. This example illustrates all three:

17

mkdir("/dir");
fd = open("/dir/file", O_CREATE|O_WRONLY); close(fd);
mknod("/console", 1, 1);

Mknod creates a special file that refers to a device. Associated with a device file are the major and minor device numbers (the two arguments to mknod), which uniquely identify a kernel device. When a process later opens a device file, the kernel diverts read and write system calls to the kernel device implementation instead of passing them to the file system.
A file’s name is distinct from the file itself; the same underlying file, called an inode, can have multiple names, called links. Each link consists of an entry in a directory; the entry contains a file name and a reference to an inode. An inode holds metadata about a file, including its type (file or directory or device), its length, the location of the file’s content on disk, and the number of links to a file.
The fstat system call retrieves information from the inode that a file descriptor refers to. It fills in a struct stat, defined in stat.h (kernel/stat.h) (https://github.com/mit-pdos/xv6-riscv/blob/riscv//kernel/stat.h) as:
#define T_DIR | 1 | // Directory

#define T_FILE | 2 | // File

#define T_DEVICE | 3 | // Device

struct stat {
int dev; | // File system’s disk device
uint ino; | // Inode number
short type; | // Type of file
short nlink; // Number of links to file uint64 size; // Size of file in bytes
};

The link system call creates another file system name referring to the same inode as an existing file. This fragment creates a new file named both a and b.

open("a", O_CREATE|O_WRONLY);
link("a", "b");

Reading from or writing to a is the same as reading from or writing to b. Each inode is identified by a unique inode number. After the code sequence above, it is possible to determine that a and b refer to the same underlying contents by inspecting the result of fstat: both will return the same inode number (ino), and the nlink count will be set to 2.
The unlink system call removes a name from the file system. The file’s inode and the disk space holding its content are only freed when the file’s link count is zero and no file descriptors refer to it. Thus adding

unlink("a");

to the last code sequence leaves the inode and file content accessible as b. Furthermore,

fd = open("/tmp/xyz", O_CREATE|O_RDWR);
unlink("/tmp/xyz");

18 is an idiomatic way to create a temporary inode with no name that will be cleaned up when the process closes fd or exits.
Unix provides file utilities callable from the shell as user-level programs, for example mkdir, ln, and rm. This design allows anyone to extend the command-line interface by adding new user-level programs. In hindsight this plan seems obvious, but other systems designed at the time of Unix often built such commands into the shell (and built the shell into the kernel).
One exception is cd, which is built into the shell cd must change the current working directory of the shell itself. If cd were run as a regular command, then the shell would fork a child process, the child process would run cd, and cd would change the child ’s working directory. The parent’s (i.e., the shell’s) working directory would not change.

## 1.5 Real world

Unix’s combination of “standard” file descriptors, pipes, and convenient shell syntax for operations on them was a major advance in writing general-purpose reusable programs. The idea sparked a culture of “software tools” that was responsible for much of Unix’s power and popularity, and the shell was the first so-called “scripting language.” The Unix system call interface persists today in systems like BSD, Linux, and macOS.
The Unix system call interface has been standardized through the Portable Operating System Interface (POSIX) standard. Xv6 is not POSIX compliant: it is missing many system calls (including basic ones such as lseek), and many of the system calls it does provide differ from the standard. Our main goals for xv6 are simplicity and clarity while providing a simple UNIX-like system-call interface. Several people have extended xv6 with a few more system calls and a simple C library in order to run basic Unix programs. Modern kernels, however, provide many more system calls, and many more kinds of kernel services, than xv6. For example, they support networking, windowing systems, user-level threads, drivers for many devices, and so on. Modern kernels evolve continuously and rapidly, and offer many features beyond POSIX.
Unix unified access to multiple types of resources (files, directories, and devices) with a single set of file-name and file-descriptor interfaces. This idea can be extended to more kinds of resources; a good example is Plan 9 [14], which applied the “resources are files” concept to networks, graphics, and more. However, most Unix-derived operating systems have not followed this route.
The file system and file descriptors have been powerful abstractions. Even so, there are other models for operating system interfaces. Multics, a predecessor of Unix, abstracted file storage in a way that made it look like memory, producing a very different flavor of interface. The complexity of the Multics design had a direct influence on the designers of Unix, who tried to build something simpler.
Xv6 does not provide a notion of users or of protecting one user from another; in Unix terms, all xv6 processes run as root.
This book examines how xv6 implements its Unix-like interface, but the ideas and concepts apply to more than just Unix. Any operating system must multiplex processes onto the underlying hardware, isolate processes from each other, and provide mechanisms for controlled inter-process communication. After studying xv6, you should be able to look at other, more complex operating

19 systems and see the concepts underlying xv6 in those systems as well.

## 1.6 Exercises

1. Write a program that uses UNIX system calls to “ping-pong” a byte between two processes over a pair of pipes, one for each direction. Measure the program’s performance, in exchanges per second.

20

# Chapter 2

# Operating system organization

A key requirement for an operating system is to support several activities at once. For example, using the system call interface described in Chapter 1 a process can start new processes with fork. The operating system must time-share the resources of the computer among these processes. For example, even if there are more processes than there are hardware CPUs, the operating system must ensure that all of the processes get a chance to execute. The operating system must also arrange for isolation between the processes. That is, if one process has a bug and malfunctions, it shouldn’t affect processes that don’t depend on the buggy process. Complete isolation, however, is too strong, since it should be possible for processes to intentionally interact; pipelines are an example. Thus an operating system must fulfill three requirements: multiplexing, isolation, and interaction.
This chapter provides an overview of how operating systems are organized to achieve these three requirements. It turns out there are many ways to do so, but this text focuses on mainstream designs centered around a monolithic kernel, which is used by many Unix operating systems. This chapter also provides an overview of an xv6 process, which is the unit of isolation in xv6, and the creation of the first process when xv6 starts.
Xv6 runs on a multi-core¹ RISC-V microprocessor, and much of its low-level functionality (for example, its process implementation) is specific to RISC-V. RISC-V is a 64-bit CPU, and xv6 is written in “LP64” C, which means long (L) and pointers (P) in the C programming language are 64 bits, but int is 32-bit. This book assumes the reader has done a bit of machine-level programming on some architecture, and will introduce RISC-V-specific ideas as they come up. A useful reference for RISC-V is “The RISC-V Reader: An Open Architecture Atlas” [13]. The user-level ISA [2] and the privileged architecture [1] are the official specifications.
The CPU in a complete computer is surrounded by support hardware, much of it in the form of I/O interfaces. Xv6 is written for the support hardware simulated by qemu’s “-machine virt” option. This includes RAM, a ROM containing boot code, a serial connection to the user’s keyboard/screen, and a disk for storage.

1By “multi-core” this text means multiple CPUs that share memory but execute in parallel, each with its own set of registers. This text sometimes uses the term multiprocessor as a synonym for multi-core, though multiprocessor can also refer more specifically to a computer with several distinct processor chips.

21

## 2.1 Abstracting physical resources

The first question one might ask when encountering an operating system is why have it at all? That is, one could implement the system calls in Figure 1.2 as a library, with which applications link. In this plan, each application could even have its own library tailored to its needs. Applications could directly interact with hardware resources and use those resources in the best way for the application (e.g., to achieve high or predictable performance). Some operating systems for embedded devices or real-time systems are organized in this way.
The downside of this library approach is that, if there is more than one application running, the applications must be well-behaved. For example, each application must periodically give up the CPU so that other applications can run. Such a cooperative time-sharing scheme may be OK if all applications trust each other and have no bugs. It’s more typical for applications to not trust each other, and to have bugs, so one often wants stronger isolation than a cooperative scheme provides. To achieve strong isolation it’s helpful to forbid applications from directly accessing sensitive hardware resources, and instead to abstract the resources into services. For example, Unix applications interact with storage only through the file system’s open, read, write, and close system calls, instead of reading and writing the disk directly. This provides the application with the convenience of pathnames, and it allows the operating system (as the implementer of the interface) to manage the disk. Even if isolation is not a concern, programs that interact intentionally (or just wish to keep out of each other’s way) are likely to find a file system a more convenient abstraction than direct use of the disk.
Similarly, Unix transparently switches hardware CPUs among processes, saving and restoring register state as necessary, so that applications don’t have to be aware of time sharing. This transparency allows the operating system to share CPUs even if some applications are in infinite loops.
As another example, Unix processes use exec to build up their memory image, instead of directly interacting with physical memory. This allows the operating system to decide where to place a process in memory; if memory is tight, the operating system might even store some of a process’s data on disk. Exec also provides users with the convenience of a file system to store executable program images.
Many forms of interaction among Unix processes occur via file descriptors. Not only do file descriptors abstract away many details (e.g., where data in a pipe or file is stored), they are also defined in a way that simplifies interaction. For example, if one application in a pipeline fails, the kernel generates an end-of-file signal for the next process in the pipeline.
The system-call interface in Figure 1.2 is carefully designed to provide both programmer convenience and the possibility of strong isolation. The Unix interface is not the only way to abstract resources, but it has proven to be a very good one.

## 2.2 User mode, supervisor mode, and system calls

Strong isolation requires a hard boundary between applications and the operating system. If the application makes a mistake, we don’t want the operating system to fail or other applications to

22 fail. Instead, the operating system should be able to clean up the failed application and continue running other applications. To achieve strong isolation, the operating system must arrange that applications cannot modify (or even read) the operating system’s data structures and instructions and that applications cannot access other processes’ memory.
CPUs provide hardware support for strong isolation. For example, RISC-V has three modes in which the CPU can execute instructions: machine mode, supervisor mode, and user mode. Instructions executing in machine mode have full privilege; a CPU starts in machine mode. Machine mode is mostly intended for configuring a computer. Xv6 executes a few lines in machine mode and then changes to supervisor mode.
In supervisor mode the CPU is allowed to execute privileged instructions: for example, enabling and disabling interrupts, reading and writing the register that holds the address of a page table, etc. If an application in user mode attempts to execute a privileged instruction, then the CPU doesn’t execute the instruction, but switches to supervisor mode so that supervisor-mode code can terminate the application, because it did something it shouldn’t be doing. Figure 1.1 in Chapter 1 illustrates this organization. An application can execute only user-mode instructions (e.g., adding numbers, etc.) and is said to be running in user space, while the software in supervisor mode can also execute privileged instructions and is said to be running in kernel space. The software running in kernel space (or in supervisor mode) is called the kernel.
An application that wants to invoke a kernel function (e.g., the read system call in xv6) must transition to the kernel; an application cannot invoke a kernel function directly. CPUs provide a special instruction that switches the CPU from user mode to supervisor mode and enters the kernel at an entry point specified by the kernel. (RISC-V provides the ecall instruction for this purpose.) Once the CPU has switched to supervisor mode, the kernel can then validate the arguments of the system call (e.g., check if the address passed to the system call is part of the application’s memory), decide whether the application is allowed to perform the requested operation (e.g., check if the application is allowed to write the specified file), and then deny it or execute it. It is important that the kernel control the entry point for transitions to supervisor mode; if the application could decide the kernel entry point, a malicious application could, for example, enter the kernel at a point where the validation of arguments is skipped.

## 2.3 Kernel organization

A key design question is what part of the operating system should run in supervisor mode. One possibility is that the entire operating system resides in the kernel, so that the implementations of all system calls run in supervisor mode. This organization is called a monolithic kernel.
In this organization the entire operating system runs with full hardware privilege. This organization is convenient because the OS designer doesn’t have to decide which part of the operating system doesn’t need full hardware privilege. Furthermore, it is easier for different parts of the operating system to cooperate. For example, an operating system might have a buffer cache that can be shared both by the file system and the virtual memory system.
A downside of the monolithic organization is that the interfaces between different parts of the operating system are often complex (as we will see in the rest of this text), and therefore it is

23

Microkernel

user | shell | File server
space

kernel
space

Send message

Figure 2.1: A microkernel with a file-system server

easy for an operating system developer to make a mistake. In a monolithic kernel, a mistake is fatal, because an error in supervisor mode will often cause the kernel to fail. If the kernel fails, the computer stops working, and thus all applications fail too. The computer must reboot to start again.
To reduce the risk of mistakes in the kernel, OS designers can minimize the amount of operating system code that runs in supervisor mode, and execute the bulk of the operating system in user mode. This kernel organization is called a microkernel.
Figure 2.1 illustrates this microkernel design. In the figure, the file system runs as a user-level process. OS services running as processes are called servers. To allow applications to interact with the file server, the kernel provides an inter-process communication mechanism to send messages from one user-mode process to another. For example, if an application like the shell wants to read or write a file, it sends a message to the file server and waits for a response.
In a microkernel, the kernel interface consists of a few low-level functions for starting applications, sending messages, accessing device hardware, etc. This organization allows the kernel to be relatively simple, as most of the operating system resides in user-level servers.
In the real world, both monolithic kernels and microkernels are popular. Many Unix kernels are monolithic. For example, Linux has a monolithic kernel, although some OS functions run as user-level servers (e.g., the windowing system). Linux delivers high performance to OS-intensive applications, partially because the subsystems of the kernel can be tightly integrated.
Operating systems such as Minix, L4, and QNX are organized as a microkernel with servers, and have seen wide deployment in embedded settings. A variant of L4, seL4, is small enough that it has been verified for memory safety and other security properties [7].
There is much debate among developers of operating systems which organization is better, and there is no conclusive evidence one way or the other. Furthermore, it depends much on what “better” means: faster performance, smaller code size, reliability of the kernel, reliability of the complete operating system (inclusing user-level services), etc.
There are also practical considerations that may be more important than the question of which organization. Some operating systems have a microkernel but run some of the user-level services in kernel space for performance reasons. Some operating systems have monolithic kernels because that is how they started and there is little incentive to move to a pure microkernel organization, because new features may be more important than rewriting the existing operating system to fit a microkernel design.
From this book’s perspective, microkernel and monolithic operating systems share many key ideas. They implement system calls, they use page tables, they handle interrupts, they support

24

File | Description
bio.c | Disk block cache for the file system.
console.c | Connect to the user keyboard and screen.
entry.S | Very first boot instructions.
exec.c | exec() system call.
file.c | File descriptor support.
fs.c | File system.
kalloc.c | Physical page allocator.
kernelvec.S | Handle traps from kernel, and timer interrupts.
log.c | File system logging and crash recovery.
main.c | Control initialization of other modules during boot.
pipe.c | Pipes.
plic.c | RISC-V interrupt controller.
printf.c | Formatted output to the console.
proc.c | Processes and scheduling.
sleeplock.c | Locks that yield the CPU.
spinlock.c | Locks that don’t yield the CPU.
start.c | Early machine-mode boot code.
string.c | C string and byte-array library.
swtch.S | Thread switching.
syscall.c | Dispatch system calls to handling function.
sysfile.c | File-related system calls.
sysproc.c | Process-related system calls.
trampoline.S | Assembly code to switch between user and kernel.
trap.c | C code to handle and return from traps and interrupts.
uart.c | Serial-port console device driver.
virtio_disk.c | Disk device driver.
vm.c | Manage page tables and address spaces.

Figure 2.2: Xv6 kernel source files.

processes, they use locks for concurrency control, they implement a file system, etc. This book focuses on these core ideas.
Xv6 is implemented as a monolithic kernel, like most Unix operating systems. Thus, the xv6 kernel interface corresponds to the operating system interface, and the kernel implements the complete operating system. Since xv6 doesn’t provide many services, its kernel is smaller than some microkernels, but conceptually xv6 is monolithic.

## 2.4 Code: xv6 organization

The xv6 kernel source is in the kernel/ sub-directory. The source is divided into files, following a rough notion of modularity; Figure 2.2 lists the files. The inter-module interfaces are defined in

| 25

0

user text
and data

user stack

heap

MAXVA | trampoline
| trapframe

Figure 2.3: Layout of a process’s virtual address space

defs.h (kernel/defs.h). (https://github.com/mit-pdos/xv6-riscv/blob/riscv//kernel/defs.h)

## 2.5 Process overview

The unit of isolation in xv6 (as in other Unix operating systems) is a process. The process abstraction prevents one process from wrecking or spying on another process’s memory, CPU, file descriptors, etc. It also prevents a process from wrecking the kernel itself, so that a process can’t subvert the kernel’s isolation mechanisms. The kernel must implement the process abstraction with care because a buggy or malicious application may trick the kernel or hardware into doing something bad (e.g., circumventing isolation). The mechanisms used by the kernel to implement processes include the user/supervisor mode flag, address spaces, and time-slicing of threads.
To help enforce isolation, the process abstraction provides the illusion to a program that it has its own private machine. A process provides a program with what appears to be a private memory system, or address space, which other processes cannot read or write. A process also provides the program with what appears to be its own CPU to execute the program’s instructions.
Xv6 uses page tables (which are implemented by hardware) to give each process its own address space. The RISC-V page table translates (or “maps”) a virtual address (the address that an RISC-V instruction manipulates) to a physical address (an address that the CPU chip sends to main memory).
Xv6 maintains a separate page table for each process that defines that process’s address space. As illustrated in Figure 2.3, an address space includes the process’s user memory starting at virtual address zero. Instructions come first, followed by global variables, then the stack, and finally a “heap” area (for malloc) that the process can expand as needed. There are a number of factors that limit the maximum size of a process’s address space: pointers on the RISC-V are 64 bits wide; the hardware only uses the low 39 bits when looking up virtual addresses in page tables; and xv6 only uses 38 of those 39 bits. Thus, the maximum address is 2

38 − 1 = At the top of the address space

26 xv6 reserves a page for a trampoline and a page mapping the process’s trapframe. Xv6 uses these two pages to transition into the kernel and back; the trampoline page contains the code to transition
in and out of the kernel and mapping the trapframe is necessary to save/restore the state of the user process, as we will explain in Chapter 4.
The xv6 kernel maintains many pieces of state for each process, which it gathers into a struct proc A process’s most important pieces of kernel state are its page table, its kernel stack, and its run state. We’ll use the notation p->xxx to refer to elements of the proc structure; for example, p->pagetable is a pointer to the process’s page table.
Each process has a thread of execution (or thread for short) that executes the process’s instructions. A thread can be suspended and later resumed. To switch transparently between processes, the kernel suspends the currently running thread and resumes another process’s thread. Much of the state of a thread (local variables, function call return addresses) is stored on the thread’s stacks. Each process has two stacks: a user stack and a kernel stack (p->kstack). When the process is executing user instructions, only its user stack is in use, and its kernel stack is empty. When the process enters the kernel (for a system call or interrupt), the kernel code executes on the process’s kernel stack; while a process is in the kernel, its user stack still contains saved data, but isn’t actively used. A process’s thread alternates between actively using its user stack and its kernel stack. The kernel stack is separate (and protected from user code) so that the kernel can execute even if a process has wrecked its user stack.
A process can make a system call by executing the RISC-V ecall instruction. This instruction raises the hardware privilege level and changes the program counter to a kernel-defined entry point. The code at the entry point switches to a kernel stack and executes the kernel instructions that implement the system call. When the system call completes, the kernel switches back to the user stack and returns to user space by calling the sret instruction, which lowers the hardware privilege level and resumes executing user instructions just after the system call instruction. A process’s thread can “block” in the kernel to wait for I/O, and resume where it left off when the I/O has finished.
p->state indicates whether the process is allocated, ready to run, running, waiting for I/O, or exiting.
p->pagetable holds the process’s page table, in the format that the RISC-V hardware expects. Xv6 causes the paging hardware to use a process’s p->pagetable when executing that process in user space. A process’s page table also serves as the record of the addresses of the physical pages allocated to store the process’s memory.
In summary, a process bundles two design ideas: an address space to give a process the illusion of its own memory, and, a thread, to give the process the illusion of its own CPU. In xv6, a process consists of one address space and one thread. In real operating systems a process may have more than one thread to take advantage of multiple CPUs.

## 2.6 Code: starting xv6, the first process and system call

To make xv6 more concrete, we’ll outline how the kernel starts and runs the first process. The subsequent chapters will describe the mechanisms that show up in this overview in more detail.

27

When the RISC-V computer powers on, it initializes itself and runs a boot loader which is stored in read-only memory. The boot loader loads the xv6 kernel into memory. Then, in machine mode, the CPU executes xv6 starting at _entry The RISC-V starts with paging hardware disabled: virtual addresses map directly to physical addresses.
The loader loads the xv6 kernel into memory at physical address 0x80000000. The reason it places the kernel at 0x80000000 rather than 0x0 is because the address range 0x0:0x80000000 contains I/O devices.
The instructions at _entry set up a stack so that xv6 can run C code. Xv6 declares space for an initial stack, stack0, in the file start.c The code at _entry loads the stack pointer register sp with the address stack0+4096, the top of the stack, because the stack on RISC-V grows down. Now that the kernel has a stack, _entry calls into C code at start
The function start performs some configuration that is only allowed in machine mode, and then switches to supervisor mode. To enter supervisor mode, RISC-V provides the instruction mret. This instruction is most often used to return from a previous call from supervisor mode to machine mode. start isn’t returning from such a call, and instead sets things up as if there had been one: it sets the previous privilege mode to supervisor in the register mstatus, it sets the return address to main by writing main’s address into the register mepc, disables virtual address translation in supervisor mode by writing 0 into the page-table register satp, and delegates all interrupts and exceptions to supervisor mode.
Before jumping into supervisor mode, start performs one more task: it programs the clock chip to generate timer interrupts. With this housekeeping out of the way, start “returns” to supervisor mode by calling mret. This causes the program counter to change to main
After main initializes several devices and subsystems, it creates the first process by calling userinit The first process executes a small program written in RISC-V assembly, make makes the first system call in xv6. initcode.S (user/initcode.S:3) (https://github.com/mit-pdos/xv6-riscv/blob/riscv//user/initcode.S#L3) loads the number for the exec system call, SYS_EXEC into register a7, and then calls ecall to re-enter the kernel.
The kernel uses the number in register a7 in syscall SYS_EXEC to sys_exec, which the kernel invokes. As we saw in Chapter 1, exec replaces the memory and registers of the current process with a new program (in this case, /init).
Once the kernel has completed exec, it returns to user space in the /init process. Init creates a new console device file if needed and then opens it as file descriptors 0, 1, and 2. Then it starts a shell on the console. The system is up.

## 2.7 Security Model

You may wonder how the operating system deals with buggy or malicious code. Because coping with malice is strictly harder than dealing with accidental bugs, it’s reasonable to view this topic as relating to security. Here’s a high-level view of typical security assumptions and goals in operating system design.
The operating system must assume that a process’s user-level code will do its best to wreck the kernel or other processes. User code may try to dereference pointers outside its allowed address space; it may attempt to execute any RISC-V instructions, even those not intended for user code;

28 it may try to read and write any RISC-V control register; it may try to directly access device hardware; and it may pass clever values to system calls in an attempt to trick the kernel into crashing or doing something stupid. The kernel’s goal to restrict each user processes so that all it can do is read/write/execute its own user memory, use the 32 general-purpose RISC-V registers, and affect the kernel and other processes in the ways that system calls are intended to allow. The kernel must prevent any other actions. This is typically an absolute requirement in kernel design. The expectations for the kernel’s own code are quite different. Kernel code is assumed to be written by well-meaning and careful programmers. Kernel code is expected to be bug-free, and certainly to contain nothing malicious. This assumption affects how we analyze kernel code. For example, there are many internal kernel functions (e.g., the spin locks) that would cause serious problems if kernel code used them incorrectly. When examining any specific piece of kernel code, we’ll want to convince ourselves that it behaves correctly. We assume, however, that kernel code in general is correctly written, and follows all the rules about use of the kernel’s own functions and data structures. At the hardware level, the RISC-V CPU, RAM, disk, etc. are assumed to operate as advertised in the documentation, with no hardware bugs.
Of course in real life things are not so straightforward. It’s difficult to prevent clever user code from making a system unusable (or causing it to panic) by consuming kernel-protected resources – disk space, CPU time, process table slots, etc. It’s usually impossible to write bug-free code or design bug-free hardware; if the writers of malicious user code are aware of kernel or hardware bugs, they will exploit them. It’s worthwhile to design safeguards into the kernel against the possibility that it has bugs: assertions, type checking, stack guard pages, etc. Finally, the distinction between user and kernel code is sometimes blurred: some privileged user-level processes may provide essential services and effectively be part of the operating system, and in some operating systems privileged user code can insert new code into the kernel (as with Linux’s loadable kernel modules).

## 2.8 Real world

Most operating systems have adopted the process concept, and most processes look similar to xv6’s. Modern operating systems, however, support several threads within a process, to allow a single process to exploit multiple CPUs. Supporting multiple threads in a process involves quite a bit of machinery that xv6 doesn’t have, including potential interface changes (e.g., Linux’s clone, a variant of fork), to control which aspects of a process threads share.

## 2.9 Exercises

1. Add a system call to xv6 that returns the amount of free memory available.

29

30

# Chapter 3

# Page tables

Page tables are the most popular mechanism through which the operating system provides each process with its own private address space and memory. Page tables determine what memory addresses mean, and what parts of physical memory can be accessed. They allow xv6 to isolate different process’s address spaces and to multiplex them onto a single physical memory. Page tables are a popular design because they provide a level of indirection that allow operating systems to perform many tricks. xv6 performs a few tricks: mapping the same memory (a trampoline page) in several address spaces, and guarding kernel and user stacks with an unmapped page. The rest of this chapter explains the page tables that the RISC-V hardware provides and how xv6 uses them.

## 3.1 Paging hardware

As a reminder, RISC-V instructions (both user and kernel) manipulate virtual addresses. The machine’s RAM, or physical memory, is indexed with physical addresses. The RISC-V page table hardware connects these two kinds of addresses, by mapping each virtual address to a physical address.
xv6 runs on Sv39 RISC-V, which means that only the bottom 39 bits of a 64-bit virtual address are used; the top 25 bits are not used. In this Sv39 configuration, a RISC-V page table is logically an array of 2

27 (134,217,728) page table entries (PTEs). Each PTE contains a 44-bit physical page number (PPN) and some flags. The paging hardware translates a virtual address by using the top 27 bits of the 39 bits to index into the page table to find a PTE, and making a 56-bit physical address whose top 44 bits come from the PPN in the PTE and whose bottom 12 bits are copied from the original virtual address. Figure 3.1 shows this process with a logical view of the page table as a simple array of PTEs (see Figure 3.2 for a fuller story). A page table gives the operating system control over virtual-to-physical address translations at the granularity of aligned chunks of 4096 (2

12) bytes. Such a chunk is called a page.
In Sv39 RISC-V, the top 25 bits of a virtual address are not used for translation. The physical address also has room for growth: there is room in the PTE format for the physical page number to grow by another 10 bits. The designers of RISC-V chose these numbers based on technology predictions. 2

39 bytes is 512 GB, which should be enough address space for applications running

31

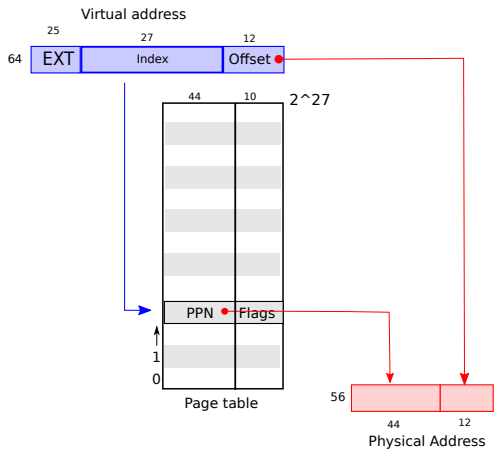
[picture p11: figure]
Virtual address; Physical Address; 12 Offset; PPN; Flags; Page table; EXT; Index

Figure 3.1: RISC-V virtual and physical addresses, with a simplified logical page table.

on RISC-V computers. 2

56 is enough physical memory space for the near future to fit may I/O devices and DRAM chips. If more is needed, the RISC-V designers have defined Sv48 with 48-bit virtual addresses [1].
As Figure 3.2 shows, a RISC-V CPU translates a virtual address into a physical in three steps. A page table is stored in physical memory as a three-level tree. The root of the tree is a 4096-byte page-table page that contains 512 PTEs, which contain the physical addresses for page-table pages in the next level of the tree. Each of those pages contains 512 PTEs for the final level in the tree. The paging hardware uses the top 9 bits of the 27 bits to select a PTE in the root page-table page, the middle 9 bits to select a PTE in a page-table page in the next level of the tree, and the bottom 9 bits to select the final PTE. (In Sv48 RISC-V a page table has four levels, and bits 39 through 47 of a virtual address index into the top-level.)
If any of the three PTEs required to translate an address is not present, the paging hardware raises a page-fault exception, leaving it up to the kernel to handle the exception (see Chapter 4). The three-level structure of Figure 3.2 allows a memory-efficient way of recording PTEs, compared to the single-level design of Figure 3.1. In the common case in which large ranges of virtual addresses have no mappings, the three-level structure can omit entire page directories. For example, if an application uses only a few pages starting at address zero, then the entries 1 through 511 of the top-level page directory are invalid, and the kernel doesn’t have to allocate pages those for 511 intermediate page directories. Furthermore, the kernel also doesn’t have to allocate pages for the bottom-level page directories for those 511 intermediate page directories. So, in this example, the three-level design saves 511 pages for intermediate page directories and 511 × 512 pages for bottom-level page directories.
Although a CPU walks the three-level structure in hardware as part of executing a load or store instruction, a potential downside of three levels is that the CPU must load three PTEs from memory to perform the translation of the virtual address in the load/store instruction to a physical address. To avoid the cost of loading PTEs from physical memory, a RISC-V CPU caches page table entries in a Translation Look-aside Buffer (TLB).

32

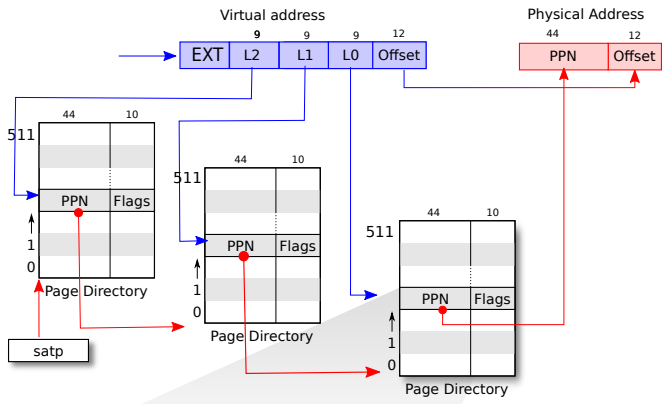
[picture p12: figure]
Virtual address; Physical Address; Offset; PPN; Flags; Page Directory; satp; EXT

Physical Page Number

6
A

5 4 3
U

2
W

1
V
63 | 8910 | 07

V
R
W
X
U

A
D
- Valid
- Readable
- Writable
- Executable
- User
- Accessed
- Dirty (0 in page directory)
D | U X | R G

A - Accessed

-G Global

RSW

Reserved for supervisor software

53
Reserved

Figure 3.2: RISC-V address translation details.

Each PTE contains flag bits that tell the paging hardware how the associated virtual address is allowed to be used. PTE_V indicates whether the PTE is present: if it is not set, a reference to the page causes an exception (i.e. is not allowed). PTE_R controls whether instructions are allowed to read to the page. PTE_W controls whether instructions are allowed to write to the page. PTE_X controls whether the CPU may interpret the content of the page as instructions and execute them. PTE_U controls whether instructions in user mode are allowed to access the page; if PTE_U is not set, the PTE can be used only in supervisor mode. Figure 3.2 shows how it all works. The flags and all other page hardware-related structures are defined in (kernel/riscv.h) (https://github.com/mit-pdos/xv6-riscv/blob/riscv//kernel/riscv.h)
To tell the hardware to use a page table, the kernel must write the physical address of the root page-table page into the satp register. Each CPU has its own satp. A CPU will translate all addresses generated by subsequent instructions using the page table pointed to by its own satp. Each CPU has its own satp so that different CPUs can run different processes, each with a private address space described by its own page table.
Typically a kernel maps all of physical memory into its page table so that it can read and write any location in physical memory using load/store instructions. Since the page directories are in physical memory, the kernel can program the content of a PTE in a page directory by writing to the virtual address of the PTE using a standard store instruction.
A few notes about terms. Physical memory refers to storage cells in DRAM. A byte of physical memory has an address, called a physical address. Instructions use only virtual addresses, which the paging hardware translates to physical addresses, and then sends to the DRAM hardware to read

33 or write storage. Unlike physical memory and virtual addresses, virtual memory isn’t a physical object, but refers to the collection of abstractions and mechanisms the kernel provides to manage

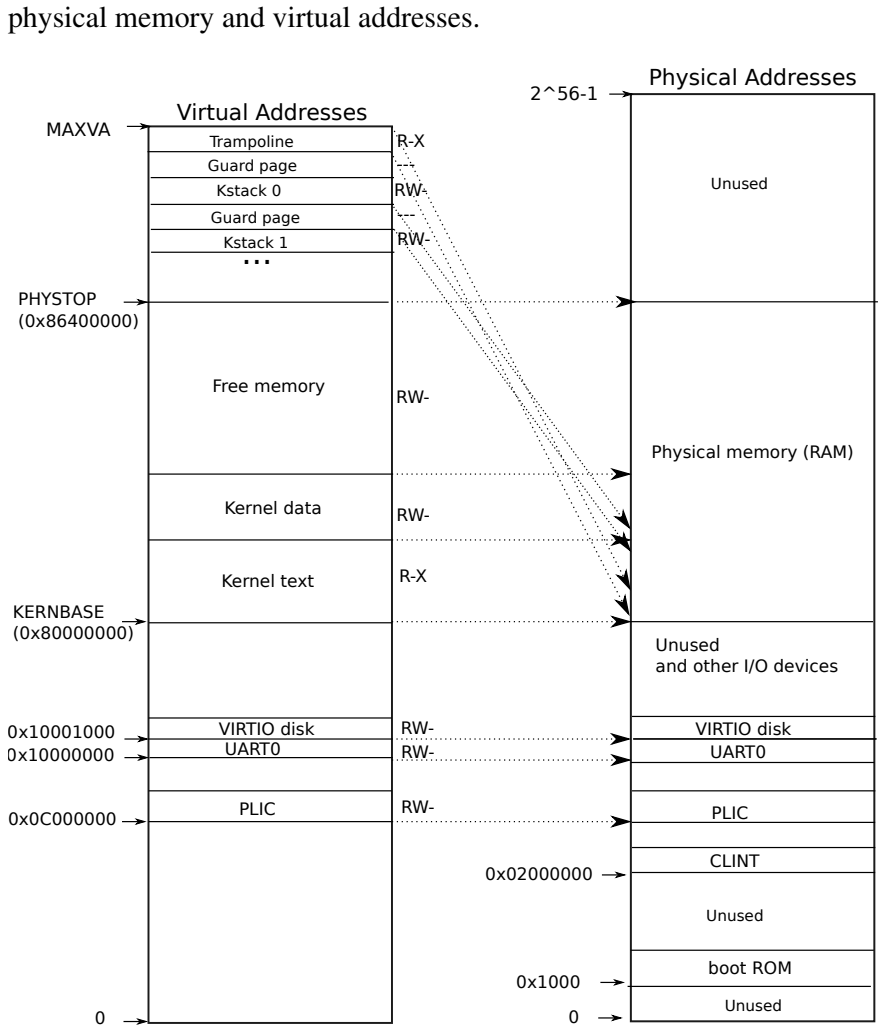
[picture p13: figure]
physical memory and virtual addresses.; Trampoline; Unused; Unused Kstack 0; Guard page; Kstack 1; Virtual Addresses; CLINT; Kernel text; boot ROM; Physical Addresses 2^56-1; Unused and other I/O devices; PLIC; UART0; VIRTIO disk; KERNBASE (0x80000000); PHYSTOP (0x86400000); MAXVA; Kernel data; Physical memory (RAM); VIRTIO disk UART0; Free memory

Figure 3.3: On the left, xv6’s kernel address space. RWX refer to PTE read, write, and execute permissions. On the right, the RISC-V physical address space that xv6 expects to see.

## 3.2 Kernel address space

Xv6 maintains one page table per process, describing each process’s user address space, plus a single page table that describes the kernel’s address space. The kernel configures the layout of its address space to give itself access to physical memory and various hardware resources at predictable virtual addresses. Figure 3.3 shows how this layout maps kernel virtual addresses to physical addresses. The file (kernel/memlayout.h) (https://github.com/mit-pdos/xv6-riscv/blob/riscv//kernel/memlayout.h) declares the constants for xv6’s kernel memory layout.

34

QEMU simulates a computer that includes RAM (physical memory) starting at physical address 0x80000000 and continuing through at least 0x86400000, which xv6 calls PHYSTOP. The QEMU simulation also includes I/O devices such as a disk interface. QEMU exposes the device interfaces to software as memory-mapped control registers that sit below 0x80000000 in the physical address space. The kernel can interact with the devices by reading/writing these special physical addresses; such reads and writes communicate with the device hardware rather than with RAM. Chapter 4 explains how xv6 interacts with devices.
The kernel gets at RAM and memory-mapped device registers using “direct mapping;” that is, mapping the resources at virtual addresses that are equal to the physical address. For example, the kernel itself is located at KERNBASE=0x80000000 in both the virtual address space and in physical memory. Direct mapping simplifies kernel code that reads or writes physical memory. For example, when fork allocates user memory for the child process, the allocator returns the physical address of that memory; fork uses that address directly as a virtual address when it is copying the parent’s user memory to the child.
There are a couple of kernel virtual addresses that aren’t direct-mapped:
- The trampoline page. It is mapped at the top of the virtual address space; user page tables have this same mapping. Chapter 4 discusses the role of the trampoline page, but we see here an interesting use case of page tables; a physical page (holding the trampoline code) is mapped twice in the virtual address space of the kernel: once at top of the virtual address space and once with a direct mapping.
- The kernel stack pages. Each process has its own kernel stack, which is mapped high so that below it xv6 can leave an unmapped guard page. The guard page’s PTE is invalid (i.e., PTE_V is not set), so that if the kernel overflows a kernel stack, it will likely cause an exception and the kernel will panic. Without a guard page an overflowing stack would overwrite other kernel memory, resulting in incorrect operation. A panic crash is preferable.

While the kernel uses its stacks via the high-memory mappings, they are also accessible to the kernel through a direct-mapped address. An alternate design might have just the direct mapping, and use the stacks at the direct-mapped address. In that arrangement, however, providing guard pages would involve unmapping virtual addresses that would otherwise refer to physical memory, which would then be hard to use.
The kernel maps the pages for the trampoline and the kernel text with the permissions PTE_R and PTE_X. The kernel reads and executes instructions from these pages. The kernel maps the other pages with the permissions PTE_R and PTE_W, so that it can read and write the memory in those pages. The mappings for the guard pages are invalid.

## 3.3 Code: creating an address space

Most of the xv6 code for manipulating address spaces and page tables resides in vm.c (kernel/vm.c:1). (https://github.com/mit-pdos/xv6-riscv/blob/riscv//kernel/vm.c#L1) The central data structure is pagetable_t, which is really a pointer to a RISC-V

35 root page-table page; a pagetable_t may be either the kernel page table, or one of the per-process page tables. The central functions are walk, which finds the PTE for a virtual address, and mappages, which installs PTEs for new mappings. Functions starting with kvm manipulate the kernel page table; functions starting with uvm manipulate a user page table; other functions are used for both. copyout and copyin copy data to and from user virtual addresses provided as system call arguments; they are in vm.c because they need to explicitly translate those addresses in order to find the corresponding physical memory.
Early in the boot sequence, main calls kvminit to create the kernel’s page table using kvmmake This call occurs before xv6 has enabled paging on the RISC-V, so addresses refer directly to physical memory. Kvmmake first allocates a page of physical memory to hold the root page-table page. Then it calls kvmmap to install the translations that the kernel needs. The translations include the kernel’s instructions and data, physical memory up to PHYSTOP, and memory ranges which are actually devices. Proc_mapstacks allocates a kernel stack for each process. It calls kvmmap to map each stack at the virtual address generated by KSTACK, which leaves room for the invalid stack-guard pages.
kvmmap calls mappages which installs mappings into a page table for a range of virtual addresses to a corresponding range of physical addresses. It does this separately for each virtual address in the range, at page intervals. For each virtual address to be mapped, mappages calls walk to find the address of the PTE for that address. It then initializes the PTE to hold the relevant physical page number, the desired permissions (PTE_W, PTE_X, and/or PTE_R), and PTE_V to mark the PTE as valid
walk mimics the RISC-V paging hardware as it looks up the PTE for a virtual address (see Figure 3.2). walk descends the 3-level page table 9 bits at the time. It uses each level’s 9 bits of virtual address to find the PTE of either the next-level page table or the final page If the PTE isn’t valid, then the required page hasn’t yet been allocated; if the alloc argument is set, walk allocates a new page-table page and puts its physical address in the PTE. It returns the address of the PTE in the lowest layer in the tree
The above code depends on physical memory being direct-mapped into the kernel virtual address space. For example, as walk descends levels of the page table, it pulls the (physical) address of the and then uses that address as a virtual address to fetch the PTE at the next level down
main calls kvminithart to install the kernel page table. It writes the physical address of the root page-table page into the register satp. After this the CPU will translate addresses using the kernel page table. Since the kernel uses an identity mapping, the now virtual address of the next instruction will map to the right physical memory address.
Each RISC-V CPU caches page table entries in a Translation Look-aside Buffer (TLB), and when xv6 changes a page table, it must tell the CPU to invalidate corresponding cached TLB entries. If it didn’t, then at some point later the TLB might use an old cached mapping, pointing to a physical page that in the meantime has been allocated to another process, and as a result, a process might be able to scribble on some other process’s memory. The RISC-V has an instruction sfence.vma that flushes the current CPU’s TLB. Xv6 executes sfence.vma in kvminithart after reloading the satp register, and in the trampoline code that switches to a user page table before returning to user space

36

To avoid flushing the complete TLB, RISC-V CPUs may support address space identifiers (ASIDs) [1]. The kernel can then flush just the TLB entries for a particular address space.

## 3.4 Physical memory allocation

The kernel must allocate and free physical memory at run-time for page tables, user memory, kernel stacks, and pipe buffers.
xv6 uses the physical memory between the end of the kernel and PHYSTOP for run-time allocation. It allocates and frees whole 4096-byte pages at a time. It keeps track of which pages are free by threading a linked list through the pages themselves. Allocation consists of removing a page from the linked list; freeing consists of adding the freed page to the list.

## 3.5 Code: Physical memory allocator

The allocator resides in kalloc.c (kernel/kalloc.c:1). (https://github.com/mit-pdos/xv6-riscv/blob/riscv//kernel/kalloc.c#L1) The allocator’s data structure is a free list of physical memory pages that are available for allocation. Each free page’s list element is a struct run Where does the allocator get the memory to hold that data structure? It store each free page’s run structure in the free page itself, since there’s nothing else stored there. The free list is protected by a spin lock The list and the lock are wrapped in a struct to make clear that the lock protects the fields in the struct. For now, ignore the lock and the calls to acquire and release; Chapter 6 will examine locking in detail.
The function main calls kinit to initialize the allocator kinit initializes the free list to hold every page between the end of the kernel and PHYSTOP. xv6 ought to determine how much physical memory is available by parsing configuration information provided by the hardware. Instead xv6 assumes that the machine has 128 megabytes of RAM. kinit calls freerange to add memory to the free list via per-page calls to kfree. A PTE can only refer to a physical address that is aligned on a 4096-byte boundary (is a multiple of 4096), so freerange uses PGROUNDUP to ensure that it frees only aligned physical addresses. The allocator starts with no memory; these calls to kfree give it some to manage.
The allocator sometimes treats addresses as integers in order to perform arithmetic on them (e.g., traversing all pages in freerange), and sometimes uses addresses as pointers to read and write memory (e.g., manipulating the run structure stored in each page); this dual use of addresses is the main reason that the allocator code is full of C type casts. The other reason is that freeing and allocation inherently change the type of the memory.
The function kfree begins by setting every byte in the memory being freed to the value 1. This will cause code that uses memory after freeing it (uses “dangling references”) to read garbage instead of the old valid contents; hopefully that will cause such code to break faster. Then kfree prepends the page to the free list: it casts pa to a pointer to struct run, records the old start of the free list in r->next, and sets the free list equal to r. kalloc removes and returns the first element in the free list.

37

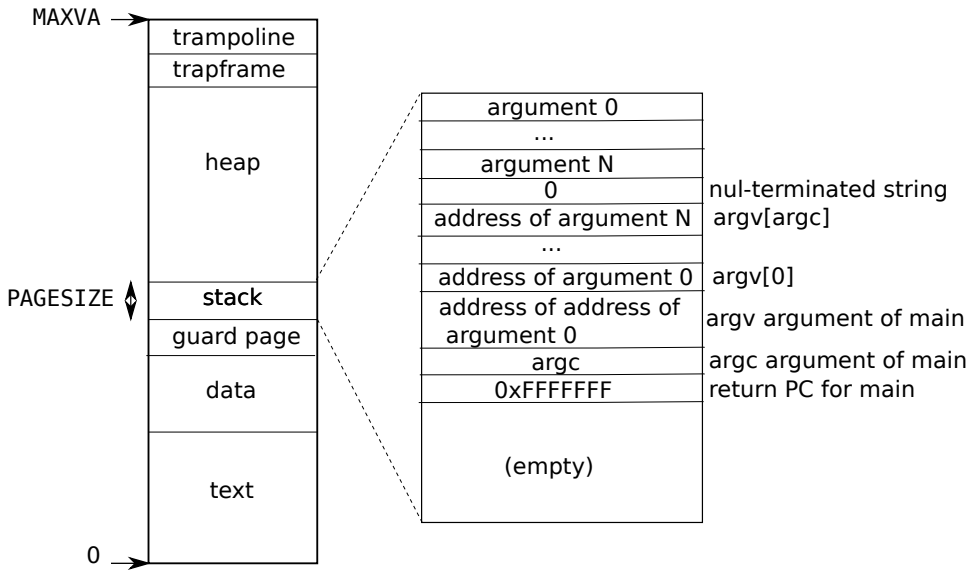
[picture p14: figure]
MAXVA; text; data; stack; heap; PAGESIZE; argument 0; argument N 0 address of argument N; address of argument 0 address of address of argument 0; 0xFFFFFFF; (empty); argc; nul-terminated string argv[argc]; argv[0]; argv argument of main; argc argument of main return PC for main; guard page; trampoline trapframe

Figure 3.4: A process’s user address space, with its initial stack.

## 3.6 Process address space

Each process has a separate page table, and when xv6 switches between processes, it also changes page tables. As Figure 2.3 shows, a process’s user memory starts at virtual address zero and can grow up to MAXVA allowing a process to address in principle 256 Gigabytes of memory.
When a process asks xv6 for more user memory, xv6 first uses kalloc to allocate physical pages. It then adds PTEs to the process’s page table that point to the new physical pages. Xv6 sets the PTE_W, PTE_X, PTE_R, PTE_U, and PTE_V flags in these PTEs. Most processes do not use the entire user address space; xv6 leaves PTE_V clear in unused PTEs.
We see here a few nice examples of use of page tables. First, different processes’ page tables translate user addresses to different pages of physical memory, so that each process has private user memory. Second, each process sees its memory as having contiguous virtual addresses starting at zero, while the process’s physical memory can be non-contiguous. Third, the kernel maps a page with trampoline code at the top of the user address space, thus a single page of physical memory shows up in all address spaces.
Figure 3.4 shows the layout of the user memory of an executing process in xv6 in more detail. The stack is a single page, and is shown with the initial contents as created by exec. Strings containing the command-line arguments, as well as an array of pointers to them, are at the very top of the stack. Just under that are values that allow a program to start at main as if the function main(argc, argv) had just been called.
To detect a user stack overflowing the allocated stack memory, xv6 places an inaccessible guard page right below the stack by clearing the PTE_U flag. If the user stack overflows and the process tries to use an address below the stack, the hardware will generate a page-fault exception because the guard page is inaccessible to a program running in user mode. A real-world operating system

38 might instead automatically allocate more memory for the user stack when it overflows.

## 3.7 Code: sbrk

Sbrk is the system call for a process to shrink or grow its memory. The system call is implemented by the function growproc growproc calls uvmalloc or uvmdealloc, depending on whether n is postive or negative. uvmalloc allocates physical memory with kalloc, and adds PTEs to the user page table with mappages. uvmdealloc calls uvmunmap which uses walk to find PTEs and kfree to free the physical memory they refer to.
xv6 uses a process’s page table not just to tell the hardware how to map user virtual addresses, but also as the only record of which physical memory pages are allocated to that process. That is the reason why freeing user memory (in uvmunmap) requires examination of the user page table.

## 3.8 Code: exec

Exec is the system call that creates the user part of an address space. It initializes the user part of an address space from a file stored in the file system. Exec opens the named binary path using namei which is explained in Chapter 8. Then, it reads the ELF header. Xv6 applications are described in the widely-used ELF format, defined in (kernel/elf.h). (https://github.com/mit-pdos/xv6-riscv/blob/riscv//kernel/elf.h) An ELF binary consists of an ELF header, struct elfhdr followed by a sequence of program section headers, struct proghdr Each proghdr describes a section of the application that must be loaded into memory; xv6 programs have only one program section header, but other systems might have separate sections for instructions and data.
The first step is a quick check that the file probably contains an ELF binary. An ELF binary starts with the four-byte “magic number” 0x7F, ‘E’, ‘L’, ‘F’, or ELF_MAGIC If the ELF header has the right magic number, exec assumes that the binary is well-formed.
Exec allocates a new page table with no user mappings with proc_pagetable allocates memory for each ELF segment with uvmalloc and loads each segment into memory with loadseg loadseg uses walkaddr to find the physical address of the allocated memory at which to write each page of the ELF segment, and readi to read from the file.
The program section header for /init, the first user program created with exec, looks like this:

# objdump -p _init

user/_init: | file format elf64-littleriscv

Program Header:
LOAD off | 0x00000000000000b0 vaddr 0x0000000000000000
| paddr 0x0000000000000000 align 2**3
filesz 0x0000000000000840 memsz 0x0000000000000858 flags rwx
STACK off | 0x0000000000000000 vaddr 0x0000000000000000
| paddr 0x0000000000000000 align 2**4
filesz 0x0000000000000000 memsz 0x0000000000000000 flags rw-

39

The program section header’s filesz may be less than the memsz, indicating that the gap between them should be filled with zeroes (for C global variables) rather than read from the file. For /init, filesz is 2112 bytes and memsz is 2136 bytes, and thus uvmalloc allocates enough physical memory to hold 2136 bytes, but reads only 2112 bytes from the file /init.
Now exec allocates and initializes the user stack. It allocates just one stack page. Exec copies the argument strings to the top of the stack one at a time, recording the pointers to them in ustack. It places a null pointer at the end of what will be the argv list passed to main. The first three entries in ustack are the fake return program counter, argc, and argv pointer.
Exec places an inaccessible page just below the stack page, so that programs that try to use more than one page will fault. This inaccessible page also allows exec to deal with arguments that are too large; in that situation, the copyout function that exec uses to copy arguments to the stack will notice that the destination page is not accessible, and will return -1.
During the preparation of the new memory image, if exec detects an error like an invalid program segment, it jumps to the label bad, frees the new image, and returns -1. Exec must wait to free the old image until it is sure that the system call will succeed: if the old image is gone, the system call cannot return -1 to it. The only error cases in exec happen during the creation of the image. Once the image is complete, exec can commit to the new page table and free the old one Exec loads bytes from the ELF file into memory at addresses specified by the ELF file. Users or processes can place whatever addresses they want into an ELF file. Thus exec is risky, because the addresses in the ELF file may refer to the kernel, accidentally or on purpose. The consequences for an unwary kernel could range from a crash to a malicious subversion of the kernel’s isolation mechanisms (i.e., a security exploit). Xv6 performs a number of checks to avoid these risks. For example if(ph.vaddr + ph.memsz < ph.vaddr) checks for whether the sum overflows a 64-bit integer. The danger is that a user could construct an ELF binary with a ph.vaddr that points to a user-chosen address, and ph.memsz large enough that the sum overflows to 0x1000, which will look like a valid value. In an older version of xv6 in which the user address space also contained the kernel (but not readable/writable in user mode), the user could choose an address that corresponded to kernel memory and would thus copy data from the ELF binary into the kernel. In the RISC-V version of xv6 this cannot happen, because the kernel has its own separate page table; loadseg loads into the process’s page table, not in the kernel’s page table.
It is easy for a kernel developer to omit a crucial check, and real-world kernels have a long history of missing checks whose absence can be exploited by user programs to obtain kernel privileges. It is likely that xv6 doesn’t do a complete job of validating user-level data supplied to the kernel, which a malicious user program might be able to exploit to circumvent xv6’s isolation.

## 3.9 Real world

Like most operating systems, xv6 uses the paging hardware for memory protection and mapping. Most operating systems make far more sophisticated use of paging than xv6 by combining paging and page-fault exceptions, which we will discuss in Chapter 4.
Xv6 is simplified by the kernel’s use of a direct map between virtual and physical addresses, and by its assumption that there is physical RAM at address 0x8000000, where the kernel expects to be

40 loaded. This works with QEMU, but on real hardware it turns out to be a bad idea; real hardware places RAM and devices at unpredictable physical addresses, so that (for example) there might be no RAM at 0x8000000, where xv6 expect to be able to store the kernel. More serious kernel designs exploit the page table to turn arbitrary hardware physical memory layouts into predictable kernel virtual address layouts.
RISC-V supports protection at the level of physical addresses, but xv6 doesn’t use that feature. On machines with lots of memory it might make sense to use RISC-V’s support for “super pages.” Small pages make sense when physical memory is small, to allow allocation and page-out to disk with fine granularity. For example, if a program uses only 8 kilobytes of memory, giving it a whole 4-megabyte super-page of physical memory is wasteful. Larger pages make sense on machines with lots of RAM, and may reduce overhead for page-table manipulation.
The xv6 kernel’s lack of a malloc-like allocator that can provide memory for small objects prevents the kernel from using sophisticated data structures that would require dynamic allocation. Memory allocation is a perennial hot topic, the basic problems being efficient use of limited memory and preparing for unknown future requests [8]. Today people care more about speed than space efficiency. In addition, a more elaborate kernel would likely allocate many different sizes of small blocks, rather than (as in xv6) just 4096-byte blocks; a real kernel allocator would need to handle small allocations as well as large ones.

## 3.10 Exercises

1. Parse RISC-V’s device tree to find the amount of physical memory the computer has.
2. Write a user program that grows its address space by one byte by calling sbrk(1). Run the program and investigate the page table for the program before the call to sbrk and after the call to sbrk. How much space has the kernel allocated? What does the PTE for the new memory contain?
3. Modify xv6 to use super pages for the kernel.
4. Modify xv6 so that when a user program dereferences a null pointer, it will receive an exception. That is, modify xv6 so that virtual address 0 isn’t mapped for user programs.
5. Unix implementations of exec traditionally include special handling for shell scripts. If the file to execute begins with the text #!, then the first line is taken to be a program to run to interpret the file. For example, if exec is called to run myprog arg1 and myprog ’s first line is #!/interp, then exec runs /interp with command line /interp myprog arg1. Implement support for this convention in xv6.
6. Implement address space randomization for the kernel.

41

42

# Chapter 4

# Traps and system calls

There are three kinds of event which cause the CPU to set aside ordinary execution of instructions and force a transfer of control to special code that handles the event. One situation is a system call, when a user program executes the ecall instruction to ask the kernel to do something for it. Another situation is an exception: an instruction (user or kernel) does something illegal, such as divide by zero or use an invalid virtual address. The third situation is a device interrupt, when a device signals that it needs attention, for example when the disk hardware finishes a read or write request.

This book uses trap as a generic term for these situations. Typically whatever code was executing at the time of the trap will later need to resume, and shouldn’t need to be aware that anything special happened. That is, we often want traps to be transparent; this is particularly important for device interrupts, which the interrupted code typically doesn’t expect. The usual sequence is that a trap forces a transfer of control into the kernel; the kernel saves registers and other state so that execution can be resumed; the kernel executes appropriate handler code (e.g., a system call implementation or device driver); the kernel restores the saved state and returns from the trap; and the original code resumes where it left off.

Xv6 handles all traps in the kernel; traps are not delivered to user code. Handling traps in the kernel is natural for system calls. It makes sense for interrupts since isolation demands that only the kernel be allowed to use devices, and because the kernel is a convenient mechanism with which to share devices among multiple processes. It also makes sense for exceptions since xv6 responds to all exceptions from user space by killing the offending program.

Xv6 trap handling proceeds in four stages: hardware actions taken by the RISC-V CPU, some assembly instructions that prepare the way for kernel C code, a C function that decides what to do with the trap, and the system call or device-driver service routine. While commonality among the three trap types suggests that a kernel could handle all traps with a single code path, it turns out to be convenient to have separate code for three distinct cases: traps from user space, traps from kernel space, and timer interrupts. Kernel code (assembler or C) that processes a trap is often called a handler; the first handler instructions are usually written in assembler (rather than C) and are sometimes called a vector.

43

## 4.1 RISC-V trap machinery

Each RISC-V CPU has a set of control registers that the kernel writes to tell the CPU how to handle traps, and that the kernel can read to find out about a trap that has occured. The RISC-V documents contain the full story [1]. riscv.h (kernel/riscv.h:1) (https://github.com/mit-pdos/xv6-riscv/blob/riscv//kernel/riscv.h#L1) contains definitions that xv6 uses. Here’s an outline of the most important registers:

- stvec: The kernel writes the address of its trap handler here; the RISC-V jumps to the address in stvec to handle a trap.
- sepc: When a trap occurs, RISC-V saves the program counter here (since the pc is then overwritten with the value in stvec). The sret (return from trap) instruction copies sepc to the pc. The kernel can write sepc to control where sret goes.
- scause: RISC-V puts a number here that describes the reason for the trap.
- sscratch: The kernel places a value here that comes in handy at the very start of a trap handler.
- sstatus: The SIE bit in sstatus controls whether device interrupts are enabled. If the kernel clears SIE, the RISC-V will defer device interrupts until the kernel sets SIE. The SPP bit indicates whether a trap came from user mode or supervisor mode, and controls to what mode sret returns.

The above registers relate to traps handled in supervisor mode, and they cannot be read or written in user mode. There is a similar set of control registers for traps handled in machine mode; xv6 uses them only for the special case of timer interrupts.
Each CPU on a multi-core chip has its own set of these registers, and more than one CPU may be handling a trap at any given time.
When it needs to force a trap, the RISC-V hardware does the following for all trap types (other than timer interrupts):
1. If the trap is a device interrupt, and the sstatus SIE bit is clear, don’t do any of the following.
2. Disable interrupts by clearing the SIE bit in sstatus.
3. Copy the pc to sepc.
4. Save the current mode (user or supervisor) in the SPP bit in sstatus.
5. Set scause to reflect the trap’s cause.
6. Set the mode to supervisor.
7. Copy stvec to the pc.

44

8. Start executing at the new pc.

Note that the CPU doesn’t switch to the kernel page table, doesn’t switch to a stack in the kernel, and doesn’t save any registers other than the pc. Kernel software must perform these tasks. One reason that the CPU does minimal work during a trap is to provide flexibility to software; for example, some operating systems omit a page table switch in some situations to increase trap performance.
It’s worth thinking about whether any of the steps listed above could be omitted, perhaps in search of faster traps. Though there are situations in which a simpler sequence can work, many of the steps would be dangerous to omit in general. For example, suppose that the CPU didn’t switch program counters. Then a trap from user space could switch to supervisor mode while still running user instructions. Those user instructions could break user/kernel isolation, for example by modifying the satp register to point to a page table that allowed accessing all of physical memory. It is thus important that the CPU switch to a kernel-specified instruction address, namely stvec.
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

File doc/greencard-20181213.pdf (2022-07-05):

Branch = 0 (BEQ rs,x0,imm) | J | BEQZ rs,imm
Arithmetic | ADD | R | ADD | rd,rs1,rs2 | Jump (uses JAL x0,imm) | J | J imm
ADD Immediate | I | ADDI | rd,rs1,imm | MoVe (uses ADDI rd,rs,0) | R | MV rd,rs
| SUBtract | R | SUB | rd,rs1,rs2 | RETurn (uses JALR x0,0,ra) | I | RET
Load Upper Imm | U | LUI | rd,imm
Add Upper Imm to PC | U | AUIPC rd,imm | Category Name | Fmt | RVC
Compare | Set < | R | SLT | rd,rs1,rs2 | Stores Store Word | CS | C.SW | rs1′,rs2′,imm
Set < Immediate | I | SLTI | rd,rs1,imm | Store Word SP | CSS | C.SWSP | rs2,imm
Set < Unsigned | R | SLTU | rd,rs1,rs2 | Float Store Word | CS | C.FSW | rs1′,rs2′,imm
Set < Imm Unsigned | I | SLTIU rd,rs1,imm | Float Store Word SP | CSS | C.FSWSP | rs2,imm
Branches | Branch = | B | BEQ | rs1,rs2,imm | Float Store Double | CS | C.FSD | rs1′,rs2′,imm
Branch ≠ | B | BNE | rs1,rs2,imm | Float Store Double SP | CSS | C.FSDSP | rs2,imm
Branch < | B | BLT | rs1,rs2,imm | Arithmetic | ADD | CR | C.ADD | rd,rs1
Branch ≥ | B | BGE | rs1,rs2,imm | ADD Immediate | CI | C.ADDI | rd,imm
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

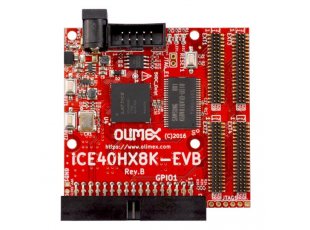
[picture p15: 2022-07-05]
doc/iCE40HX8K-EVB-1.jpg

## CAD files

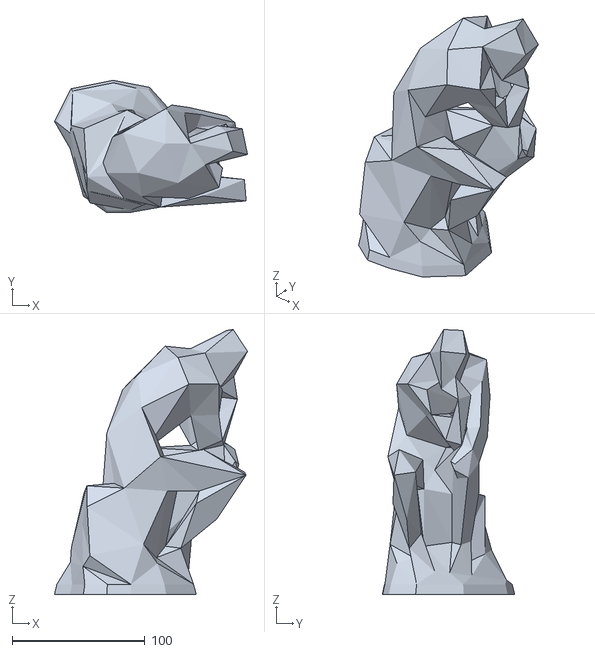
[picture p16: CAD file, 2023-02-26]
cube/thinker.stl
145.7 x 100.0 x 200.0

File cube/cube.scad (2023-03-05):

//Parameter
cube_a = 100;       //Kantenlänge außen
cube_d = 2;         //Dicke der Wand
boden_d = 4;        //Boden Dicke


rip_h = 5;          //Rippe Abstand
rip_d = 1;          //Rippen Dicke
rip_l = 2;          //Rippen Länge


schienen_d = 2.4;               //Dicke der Schienen
schienen_a = 60;                //Abstand der Schienen
schienen_loch = 2.4;            //Lochdurchmesser       
rear_loch = 3;            //Lochdurchmesser       

rand=0.7;                       //Bevel

$fn=32;                         //Ecken für Kreise

//Hilfsparameter
rip_a = cube_a;
rip_b = rip_d+rip_l;          
rip_i = cube_a - 2 * rip_b;
cool_h = 6*rip_h + 3 * rip_d;   //gesamte Kühlrippen Höhe
schienen_l = cube_a - 2*boden_d;    
boden_h = (cube_a-cool_h)/2;    
cube_i = cube_a-2*rip_b-2*cube_d;

//Was soll gezeigt werden?
item="trayThinker.stl";
print(item);

//Select the item to print
module print(item="all.stl"){
   if (item=="front.stl") front();
   if (item=="rear.stl") rear();
   if (item=="rip.stl") rip();
   if (item=="rip_center.stl") rip_center();
   if (item=="trayICE40.stl") trayICE40();
   if (item=="tray32u4.stl") tray32u4();
   if (item=="traySDCard.stl") traySDCard();
   if (item=="trayThinker.stl") trayThinker();
   if (item=="logo.stl") logo_plate();
   if (item=="all.stl"){
        cool();
        translate([0,0,-100]) front();
        translate([0,0,50])   rear();
        translate([150,0,0])  trayICE40();
        translate([-150,0,0]) tray32u4();
        translate([0,-150,0]) trayThinker();
        translate([0,150,0])  traySDCard();
   }
} 


//Logo on small plate
module logo_plate(){
    difference(){
        cubebevel(15.8,15.8,1.8,0.3);
        translate([0,0,0.9])mirror([0,0,1])logo(6);
    }
}
    
//The cube logo with an X
module logo(laenge){
    dicke=laenge*0.133;
    translate([0.05*laenge,0.2*laenge,0])rotate(28)
    union(){
        //The X
        rotate(90) prism3(0.6*laenge,dicke,dicke,1.3);
        rotate(90) prism3(0.6*laenge,dicke,dicke,-1.3);
        
        //cube front
        translate([0,laenge/2,0]) prism2(laenge,dicke,dicke);
        translate([0,-laenge/2,0]) prism2(laenge,dicke,dicke);
        translate([laenge/2,0,0])rotate(90) prism2(laenge,dicke,dicke);
        translate([-laenge/2,0,0])rotate(90) prism2(laenge,dicke,dicke);
        //cube rear
        translate([-0.8*laenge,-0.3*laenge,0])rotate(90) prism2(laenge,dicke,dicke);
        translate([-0.3*laenge,-0.8*laenge,0]) prism2(laenge,dicke,dicke);
        //cube front to rear
        translate([-0.65*laenge,0.35*laenge,0])rotate(45) prism(0.42*laenge,1.4*dicke,dicke);
        translate([-0.65*laenge,-0.65*laenge,0])rotate(45) prism(0.42*laenge,1.4*dicke,dicke);
        translate([0.35*laenge, -0.65*laenge,0])rotate(-135) prism(0.42*laenge,1.4*dicke,dicke);
    }
}

//Tray for the SD Card Reader
module traySDCard(){
    cubebevel(schienen_a-2*schienen_d-0.4,schienen_l,2,rand);
    translate([0,-(schienen_l-2)/2,2]) cube([40,2,2],center=true);
    
    translate([0,18.5,0])difference(){
        union(){
            translate([18,4,1]) cylinder(5,3,3);
            translate([-18,4,1]) cylinder(5,3,3);
            translate([0,0,(2+9)/2]) cube([38,35,9],center=true);
        }
        translate([0,2,1+9/2]) cube([30,31,9],center=true);
        translate([0,2,9]) cube([38,31,2],center=true);
        translate([0,2,1+6]) cube([34,31,2],center=true);
        translate([0,4,1+6]) cube([38,5,2],center=true);
        translate([18,4,1]) cylinder(5,1.2,1.2);
        translate([-18,4,1]) cylinder(5,1.2,1.2);
    }
}

//Tray with the Thinker
module trayThinker(){
    cubebevel(schienen_a-2*schienen_d-0.4,schienen_l,2,rand);
    translate([0,-(schienen_l-2)/2,2]) cube([40,2,2],center=true);
    translate([0,-10,1])rotate(90)scale(0.28)import("thinker.stl", convexity = 5);
}

//Tray for Olimexino 32u4
module tray32u4(){
    cubebevel(cube_i-0.4,schienen_l,2,rand);
    translate([0,-(schienen_l-2)/2,2])cube([60,2,2],center=true);
    translate([-11,-42,1]) nupsi(5,6,2.4);
    translate([37,-42,1]) nupsi(5,6,2.4);
    translate([4,8.5,1]) nupsi(5,6,2.4);
    translate([32,8.5,1]) nupsi(5,6,2.4);
}

//Tray for the iCE40HX8K-EVB
module trayICE40(){
    cubebevel(cube_i-0.4,schienen_l,2,rand);
    translate([0,-(schienen_l-2)/2,2]) cube([60,2,2],center=true);
    translate([-30.5,-23,1]) nupsi(3,6,2.4);
    translate([13.5,-23,1]) nupsi(3,6,2.4);
    translate([-30.5,16,1]) nupsi(3,6,2.4);
    translate([13.5,16,1]) nupsi(3,6,2.4);
}

//Litte cylinder for screws
module nupsi(h,a,i){
    difference(){
        cylinder(h,a/2,a/2);
        cylinder(h,i/2,i/2);
    }
}

//rear part of cube
module rear(){
    translate([0,0,(cool_h+boden_h-boden_d)/2])
        rahmen(cube_a,cube_i+2*cube_d,boden_h-boden_d,rand);
    translate([0,0,(cool_h-rip_d)/2])
        rahmen(cube_a-2*rip_l,cube_i+2*cube_d,rip_d,0);
    translate([0,0,cube_a/2-boden_d/2])
    difference(){
        bodenplatte();
        holes();
        translate([33,-8.5,0])
        cube([9,52,4],center=true);
        translate([-31,-30.5,0])
        cube([11,9,4],center=true);
        translate([-34.5,-15.5,0])
        cube([3,8,4],center=true);
        translate([-34.3,-2.5,0])
        cube([4.5,9,4],center=true);
        translate([-34.3,-2.5,1])
        cube([9,12.5,2],center=true);
    }
    
}

//Four holes for rear part 
module holes(){
    hole();
    mirror([0,1,0]) hole();
    mirror([0,1,0]) mirror([1,0,0]) hole();
    mirror([1,0,0]) hole();
}

//Single hole for the screw
module hole(){
    translate([schienen_a/2,(cube_i-2*schienen_d)/2,0])
        cylinder(boden_d,schienen_loch/2,rear_loch/2,center=true); 
    translate([schienen_a/2,(cube_i-2*schienen_d)/2,0.75])
        cylinder(2.5,schienen_loch,rear_loch,center=true);
}

//Die Bodenplatte für rear und front
module bodenplatte(){
    difference(){
        cubebevel(cube_a,cube_a,boden_d,rand);
        translate([0,22.5,(boden_d-1)/2])
            cube([52,47,1],center=true);
        beveltop(cube_a,cube_a,boden_d,rand);
    }
    for (a=[1.5:3:43.5])
        translate([0,a,boden_d/2-1])prism(50, 3, 1);
}

//Front part of Cube
module front(){
    translate([0,0,(-cube_a+boden_h+boden_d)/2])
        rahmen(cube_a,cube_i,boden_h-boden_d,rand);
    translate([0,0,(-cool_h+rip_d)/2])
        rahmen(cube_a-2*rip_l,cube_i,rip_d,0);
    difference(){
        rahmen(cube_a-2*rip_b,cube_i,cube_a-2*boden_d,rand);
        beveltop(cube_a-2*rip_b,cube_a-2*rip_b,cube_a-2*boden_d,rand);
    }
    //Bodenplatte
    translate([0,0,(-cube_a+boden_d)/2])mirror([0,0,1])
        difference(){
            union(){
                bodenplatte();
                translate([0,35.5,-4])cube([40,10,4],center=true);
            }
            //Schlitz für SD
            translate([0,34.5,-2]) cube([26,3,boden_d+4],center=true);
            translate([0,35.5,-3]) cube([36,6,6],center=true);
            //Logo
            translate([0,-37,2])mirror([1,0,0])mirror([0,0,1])logo(6);
        }
    //rahmen halter
    four();
}


//Rahmen halter vierfach
module four(){
    streben();
    mirror([0,1,0]) streben();
    mirror([0,1,0]) mirror([1,0,0]) streben();
    mirror([1,0,0]) streben();
}

//Einzelne Strebe
module streben(){
    translate([(cube_i-3*schienen_d)/2,(cube_i-schienen_d)/2,0])
        cube([schienen_d,schienen_d,schienen_l],center=true);
    translate([schienen_a/2,(cube_i-2*schienen_d)/2,0])
        difference(){
            cube([2*schienen_d,2*schienen_d,schienen_l],center=true);
            translate([0,0,(schienen_l-6)/2])
            cylinder(6,schienen_loch/2,schienen_loch/2,center=true);    
        }
    translate([schienen_a/2-1.5*schienen_d,(cube_i-3*schienen_d)/2,0])
        cube([schienen_d,schienen_d,schienen_l],center=true);
}

//Kühlrippen
module cool(){
    delta=(rip_d+rip_h)/2;
    //for(a=[1,3,5]){
    for(a=[1,3,5]){
    translate([0,0,delta+a*rip_h])mirror([0,0,1])rip();
    translate([0,0,-delta-a*rip_h])rip();
    }
    rip_center();
}

//Mittlere Kühlrippe
module rip_center(){
    rahmen(rip_a,rip_i,rip_d,rand);
}

//Kühlrippe
module rip(){
    rahmen(rip_a-2*rip_l,rip_i,rip_h);
     translate([0,0,(-rip_h+rip_d)/2])
        rahmen(rip_a,rip_i,rip_d,rand);
}

//Cubischer Torus
module rahmen(aussen,innen,hoehe,rand){
    difference(){
        cubebevel(aussen,aussen,hoehe,rand);
        cube([innen,innen,hoehe],center=true);  
    }
}

//Cube with Bevel
module cubebevel(x,y,hoehe,rand){
        difference(){
        cube([x,y,hoehe],center=true);
        translate([x/2,-y/2,-hoehe/2])
            rotate([0,270,0])
                bevel(hoehe,rand);
        translate([x/2,y/2,-hoehe/2])
            rotate([0,270,90])
                bevel(hoehe,rand);
        translate([-y/2,y/2,-hoehe/2])
            rotate([0,270,180])
                bevel(hoehe,rand);
        translate([-x/2,-y/2,-hoehe/2])
            rotate([0,270,270])
                bevel(hoehe,rand);   
    }
}
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

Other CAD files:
cube/files/cube.blend
cube/files/front.blend
cube/files/logo1.blend
cube/files/logo2.blend
cube/files/logo3.blend
cube/files/nothing.blend
cube/files/rear.blend
cube/files/rip.blend
cube/files/rip_center.blend
cube/files/tray_32u4.blend
cube/files/tray_SD.blend
cube/files/tray_Thinker.blend
cube/files/tray_ice40.blend

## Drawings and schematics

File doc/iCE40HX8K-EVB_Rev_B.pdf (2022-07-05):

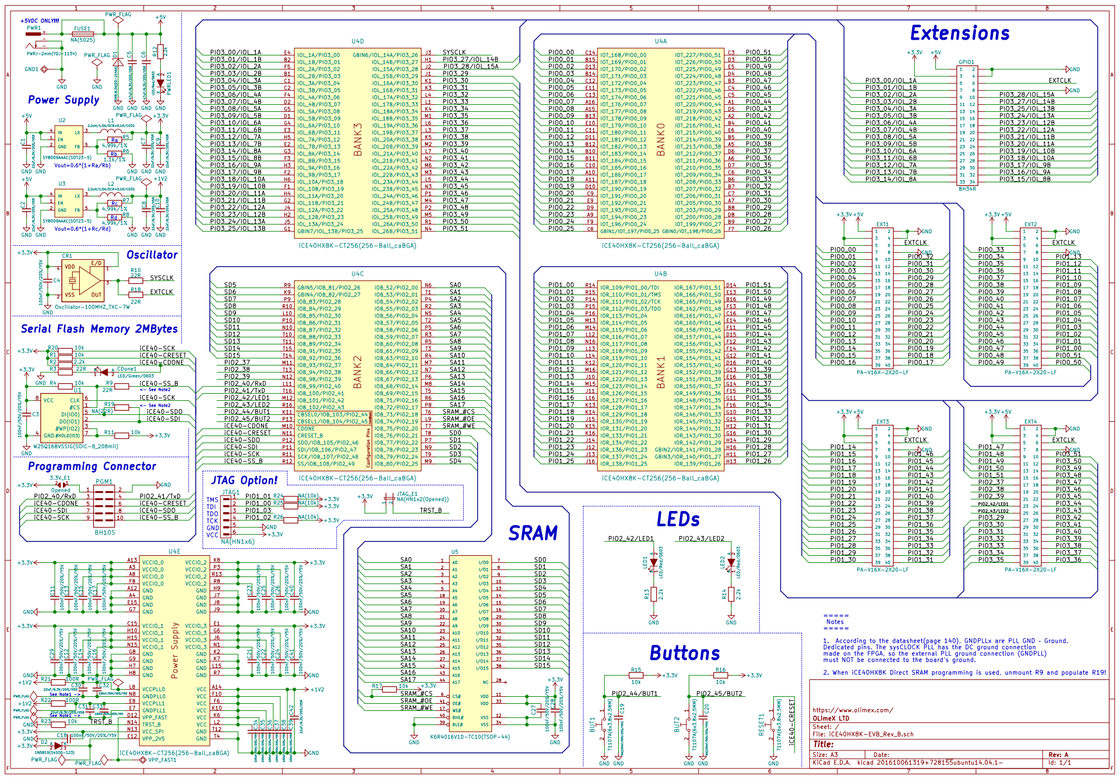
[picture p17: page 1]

2 PWRLED1 LED/Red/0603 R12 2.2k GND C1 22uF/6.3V/20%/X5R GND
iCE40HX8K-CT256(256-Ball_caBGA) BANK3

https://www.olimex.com/
Id: 1/1 Title: File: iCE40HX8K-EVB_Rev_B.sch Sheet: / OLimeX LTD

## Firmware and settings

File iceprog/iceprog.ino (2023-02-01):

/*
 *  iceprog -- firmware scetch for Arduino based Lattice iCE programmers
 *
 *  Chris B. <chris@protonic.co.uk> @ Olimex Ltd. <c> 2017
 *  
 *  Permission to use, copy, modify, and/or distribute this software for any
 *  purpose with or without fee is hereby granted, provided that the above
 *  copyright notice and this permission notice appear in all copies.
 *  
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
 *  Relevant Documents:
 *  -------------------
 *  http://www.latticesemi.com/~/media/Documents/UserManuals/EI/icestickusermanual.pdf
 *  http://www.micron.com/~/media/documents/products/data-sheet/nor-flash/serial-nor/n25q/n25q_32mb_3v_65nm.pdf
 *  http://www.ftdichip.com/Support/Documents/AppNotes/AN_108_Command_Processor_for_MPSSE_and_MCU_Host_Bus_Emulation_Modes.pdf
 *  https://www.olimex.com/Products/FPGA/iCE40/iCE40HX1K-EVB/
 *  https://github.com/Marzogh/SPIFlash  
 */

#include <SPI.h>

// The demo uses SPIFlash v2.2.0, its files are included in the project folders the author is Prajwal Bhattaram - Marzogh

#include "SPIFlash.h"

#define LED 17
#define CDONE 3
#define RESET 2
#define UEXT_POWER 8
#define CS  13

//commands list
#define READ_ID   0x9F
#define PWR_UP    0xAB
#define PWR_DOWN  0xB9
#define WR_EN   0x06
#define BULK_ERASE  0xC7
#define SEC_ERASE 0xd8
#define PROG    0x02
#define READ    0x03
#define READ_ALL    0x83
#define CMD_ERROR 0xee
#define READY   0x44
#define EMPTY    0x45

#define FEND  0xc0
#define FESC  0xdb
#define TFEND   0xdc
#define TFESC  0xdd

#define cselect digitalWrite(CS,LOW)
#define deselect digitalWrite(CS,HIGH)

//Toggle iceprogduino with serial bridge by pressing the HWB button
#define HWB (PINE & B00000100)==0     // Check if the button has been pressed
#define HWB_INPUT DDRE &= B11111011   // Initialize the port
#define LED_G 7                       // The GREEN  LED is on Pin 7
#define LED_Y 9                       // The YELLOW  LED is on Pin 9
boolean isProg;

uint8_t rxframe[512], txframe[512], fcs,rfcs;
uint8_t membuf[256];
uint8_t data_buffer[256];
uint16_t txp;
uint32_t maxPage;
bool escaped;
SPIFlash flash(CS);

void secerase(uint32_t sector);
void decodeFrame(void);
void writepage(int pagenr);
bool readSerialFrame(void);
void flash_bulk_erase(void);
void SendID(void);
void sendframe();
void startframe(uint8_t command);
void addbyte(uint8_t newbyte);
void readAllPages(void);
void readpage(uint16_t adr);

// FRAME:   <FEND><CMD>{data if any}<FCS(sume of all bytes = 0xFF)><FEND>
// if FEND, FESC in data - <FEND>=<FESC><TFEND>;  <FESC>=<FESC><TFESC>

void setup() {
  // put your setup code here, to run once:
    // Power Up UEXT
   pinMode(CDONE,INPUT);
   pinMode(RESET,OUTPUT);
   pinMode(LED,OUTPUT);
   digitalWrite(LED,0);
   pinMode(CS,OUTPUT);
   digitalWrite(CS,HIGH);
   pinMode(UEXT_POWER, OUTPUT);
   digitalWrite(UEXT_POWER, HIGH);
   delay(1000);
   digitalWrite(UEXT_POWER, LOW);
   delay(500);
   digitalWrite(RESET, HIGH);
   Serial.begin(230400);
   while (!Serial);

   isProg=false;
   HWB_INPUT;                   // Initialize HWB
   Serial1.begin(115200);
   pinMode(LED_Y,OUTPUT);   
   pinMode(LED_G,OUTPUT);
   updateLED();
}

void updateLED(){
   digitalWrite(LED_Y,isProg);  //Yellow LED is Prog
   digitalWrite(LED_G,!isProg); //Green LED is Bridge
}

void loop(){
  if (isProg) loopProg();
  else loopBridge();
  if (HWB) {
    isProg = !isProg;
    updateLED();
    delay(1000);
  }
}

void loopBridge(){
  // read from port 1, send to port 0:
  if (Serial1.available()) {
    int inByte = Serial1.read();
    Serial.write(inByte);
  }

  // read from port 0, send to port 1:
  if (Serial.available()) {
    int inByte = Serial.read();
    if (inByte==FEND){
      isProg=true;
      updateLED();
    }
    Serial1.write(inByte);
  }
}

void loopProg() {    
  if (readSerialFrame())
  {
    decodeFrame();
    if (rfcs==0xff)
    {
  digitalWrite(RESET, LOW);

  switch (rxframe[0]){
    
    case FEND:
    break;
    
    case READ_ID:
    SendID();
    break;
    
    case BULK_ERASE:
    flash_bulk_erase();
    break;

    case SEC_ERASE:
    flash.powerUp();
    secerase((rxframe[1]<<8) | rxframe[2]);
    flash.powerDown();

    break;
    
    case READ:
    flash.powerUp();
    readpage((rxframe[1]<<8) | rxframe[2]);
    flash.powerDown();
    break;
    
    case READ_ALL:
    readAllPages();
    break;   
    
    case PROG:
    writepage((rxframe[1]<<8) | rxframe[2]);
    break;
    
    default:
    break;


  }//switch
   digitalWrite(RESET, HIGH);  

    } 
   
  }
}


void secerase(uint32_t  sector){
  flash.eraseBlock64K(sector<<8);
  startframe(READY);
  sendframe();
  
}
void decodeFrame(void){
  int x,y;
  escaped = false;
  y = 1;
  rfcs = rxframe[1];
  rxframe[0]=rxframe[1];
     for (x=2;x<512;x++)
   {
     switch (rxframe[x]){

      case FEND:
      x = 513;
      break;

     case FESC:
     escaped = true;
     break;

     case TFEND:
     if (escaped)
     {
     rxframe[y++] = FEND;
     rfcs+=FEND;
     escaped = false;
     }
     else 
     {
      rxframe[y++]=TFEND;
      rfcs+=TFEND;
     }
    
     break;

     case TFESC:
     if (escaped)
     {
     rxframe[y++]=FESC;
     rfcs+=FESC;
     escaped = false;
     }
     else 
     {
      rxframe[y++]=TFESC;
      rfcs+=TFESC;
     }

     break;    

     default:
     escaped = false;
     rxframe[y++] = rxframe[x];
     rfcs+=rxframe[x];
      break;
     }
    
   }
 
}

void writepage(int pagenr){
int x;
flash.powerUp();

for (x=0; x<256;x++)
              membuf[x]=rxframe[x+3];

flash.writePage(pagenr,membuf);
flash.readPage(pagenr,data_buffer);
flash.powerDown();

 for (int a = 0; a < 256; a++)
      if (data_buffer[a] != membuf[a])
                  return;

  startframe(READY);
  sendframe();

  
}



//Reads a frame from Serial
bool readSerialFrame(void) 
{
  Serial.setTimeout(50);
  
  if (!Serial)
  Serial.begin(230400);
  // Serial.begin(1000000);
  while (Serial.available()) {
    Serial.readBytesUntil(FEND,rxframe,512);
    //if (rxframe[0]!=FEND)
                return true;
  }
  return false;
}
void flash_bulk_erase(void)
{
 flash.powerUp();
 flash.eraseChip();
 flash.powerDown();
  startframe(READY);
  addbyte(BULK_ERASE);
  sendframe();
}

void SendID(void)
{
  
 flash.powerUp();
      uint32_t JEDEC = flash.getJEDECID();
 flash.powerDown();
      startframe(READ_ID);
      addbyte(JEDEC >> 16);
      addbyte(JEDEC >> 8);
      addbyte(JEDEC >> 0);
      sendframe();


} 


void sendframe(){
  fcs = 0xff - fcs;
 addbyte(fcs);
 txframe[txp++] = FEND;
 Serial.write(txframe,txp);
  
}


void startframe(uint8_t command){
  txframe[0]=FEND;
  txframe[1]=command;
  txp = 2;
  fcs = command;
}
void addbyte(uint8_t newbyte)
{
fcs+=newbyte;
if (newbyte == FEND)
{
  txframe[txp++] = FESC;
  txframe[txp++] = TFEND;
} else
  if (newbyte == FESC)
  {
  txframe[txp++] = FESC;
  txframe[txp++] = TFESC;
  } else  
   txframe[txp++] = newbyte;

}


void readAllPages(void){
flash.powerUp();
maxPage=0x2000;
delay(10);
int p;
for (p=0;p<maxPage;p++)
              readpage(p);
  startframe(READY);
  sendframe();
//
   flash.powerDown();
}


void  readpage(uint16_t adr){

bool sendempty = true;  
//delay(5);

 flash.readPage(adr,data_buffer);

 for (int a = 0; a < 256; a++){
  if (data_buffer[a] != 0xff){
      startframe(READ);
      addbyte(adr >> 8);
      addbyte(adr >> 0);
      for (int b = 0;b<256;b++)
                addbyte(data_buffer[b]);
      sendframe();
      sendempty=false;
    break;
    
  }
  
 }
 if (sendempty){
  startframe(EMPTY);
  addbyte(adr >> 8);
  addbyte(adr >> 0);  
  sendframe();
 }
}

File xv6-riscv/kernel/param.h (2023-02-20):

#define NPROC         8  // maximum number of processes
#define NCPU          1  // maximum number of CPUs
#define NOFILE        8  // open files per process
#define NFILE         8  // open files per system
#define NINODE        8  // maximum number of active i-nodes
#define NDEV          8  // maximum major device number
#define ROOTDEV       1  // device number of file system root disk
#define MAXARG       16  // max exec arguments
#define MAXOPBLOCKS  16  // max # of blocks any FS op writes
#define LOGSIZE      (MAXOPBLOCKS)  // max data blocks in on-disk log
#define NBUF         (MAXOPBLOCKS)  // size of disk block cache
#define FSSIZE       2000  // size of file system in blocks
#define MAXPATH      32   // maximum file path name

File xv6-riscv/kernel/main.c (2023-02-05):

#include "types.h"
#include "param.h"
#include "memlayout.h"
#include "riscv.h"
#include "defs.h"
#include "sdcard.h"

volatile static int started = 0;

// start() jumps here in supervisor mode on all CPUs.
void
main()
{
  if(cpuid() == 0){
    consoleinit();
    printfinit();
    printf("\n");
    printf("xv6 kernel is booting\n");
    printf("\n");
    kinit();         // physical page allocator
    kvminit();       // create kernel page table
    kvminithart();   // turn on paging
    procinit();      // process table
    trapinit();      // trap vectors
    trapinithart();  // install kernel trap vector
    plicinit();      // set up interrupt controller
    plicinithart();  // ask PLIC for device interrupts
    binit();         // buffer cache
    iinit();         // inode table
    fileinit();      // file table
	spi_init();
//    virtio_disk_init(); // emulated hard disk
    userinit();      // first user process
    __sync_synchronize();
    started = 1;
  } else {
    while(started == 0)
      ;
    __sync_synchronize();
    printf("hart %d starting\n", cpuid());
    kvminithart();    // turn on paging
    trapinithart();   // install kernel trap vector
    plicinithart();   // ask PLIC for device interrupts
  }

  scheduler();        
}

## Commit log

2022-07-05 lisp let
    [button-Cube.stl, button.blend, cube.blend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]
2022-07-30 lisp add ons
    [front-Cube.stl, front.blend, front1-Cube.stl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]
2022-09-01 lisp examples
    [front1.blend]
2023-01-19 :changed cube
    [front-Cube.stl, front1-Cube.stl, rear.blend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]
2023-01-23 changed cube with logo
    [front.blend, rear.blend, rip.blend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]
2023-01-24 logo fit!
    [logo1.blend, logo2.blend, logo3.blend]
2023-01-24 logo fits
    [logo1.blend, logo2.blend, logo3.blend]
2023-01-27 sd card slot thicker
    [front.blend, logo1.blend, logo2.blend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]
2023-01-27 user64 from origin
    [front1.blend]
2023-01-29 simplified logo
    [logo1.blend, logo2.blend, logo3.blend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]
2023-01-31 changed connector to SD-Card
2023-01-31 added thinker
    [tray_Thinker.blend]
2023-02-01 changed ice40 tray with connector outside
    [tray_ice40.blend]
2023-02-01 changed rear
    [rear.blend]
2023-02-01 changed uart to uart64. Working without IETX??
2023-02-03 changed cube
    [rear.blend, tray_Thinker.blend, tray_ice40.blend]
2023-02-12 version v1.2
    [tray_ETH.blend]
2023-02-15 corrected cube
    [logo1.blend, logo2.blend, logo3.blend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]
2023-02-17 changed toolchain apio to oss-cad-suite
2023-02-18 added connector dia
2023-02-23 added cube.scad
    [cube.scad]
2023-02-24 cube grob
    [cube.scad]
2023-02-26 changed cube.scad
    [cube.scad]
2023-02-26 Makefile for cube.scad
    [cube.scad, thinker.stl]
2023-02-27 moved cube.scad to cube
    [cube.scad, thinker.stl]
2023-02-27 added firmware.hex to Makefile of fpga
    [cube.scad, thinker.stl]
2023-02-27 changed Makefile cube.scad
    [cube.scad]
2023-02-28 added logo
    [cube.scad]
2023-02-28 added bevel
    [cube.scad]
2023-03-01 added logoplate
    [cube.scad]
2023-03-01 added comments to cube.scad
    [cube.scad]
2023-03-02 added leds for sagar
    [main.c]
2023-03-02 added X
    [cube.scad]
2023-03-02 removed fpga-leds
2023-03-03 gtkwave from oss-cad-suite, logo X
    [cube.scad]
2023-03-03 holes of rear
    [cube.scad]
2023-03-04 added no-warn-rwx-segment
    [cube.scad]
2023-03-05 little details on cube.scad
    [cube.scad]
